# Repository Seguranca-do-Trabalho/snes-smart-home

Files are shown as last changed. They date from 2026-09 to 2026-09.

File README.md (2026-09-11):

# Super Famicom / SNES Smart Home & Diagnostics Cartridge V1.0

Custom smart cartridge for the **Super Famicom / SNES (SHVC-001)** console with bidirectional **Home Assistant** integration, bench telemetry, Wi-Fi 6 / BLE / Thread connectivity, and industrial expansion bus.

Designed to run on real hardware and emulators, with a 100% data-driven architecture: **the ROM does not assume beforehand how many or what devices exist in the house**.

---

## 📷 Photos and ROM Screenshots on Super Nintendo

| Page 1: Lighting, Garage, Climate and Fan | Page 2: Lock, Spotify, Alarm and Switch |
|:---:|:---:|
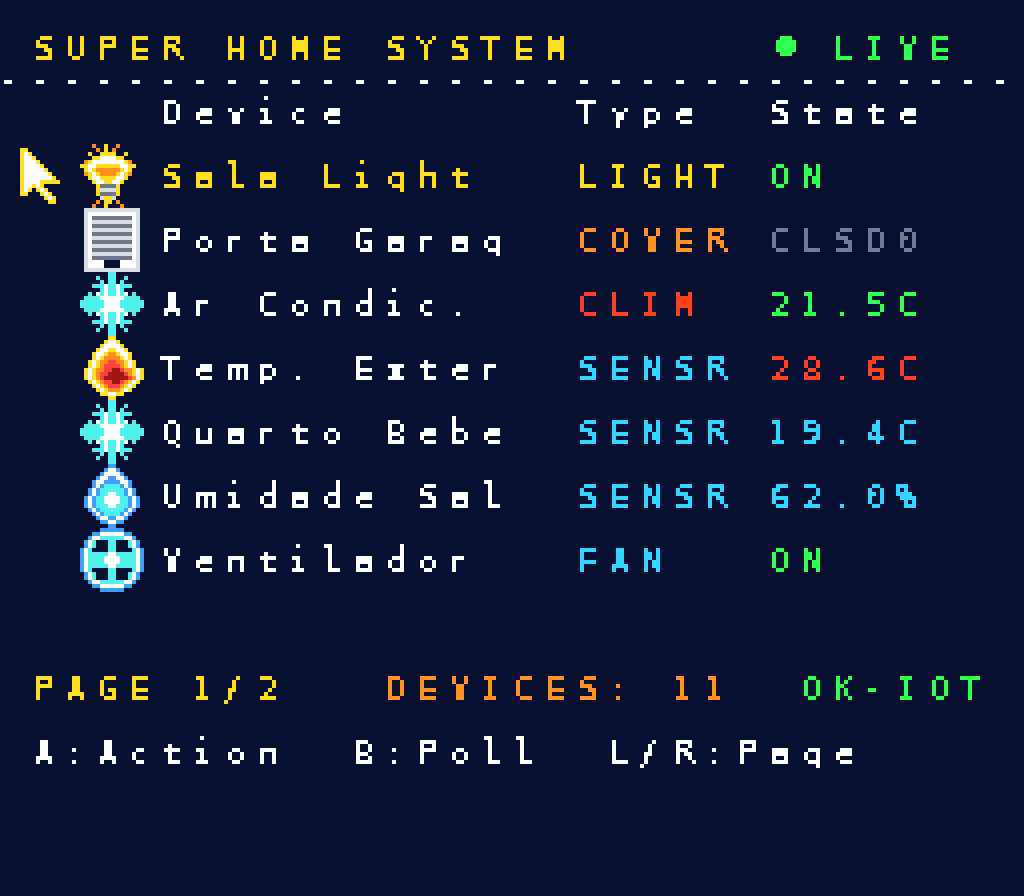
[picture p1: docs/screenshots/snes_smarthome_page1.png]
Page 1
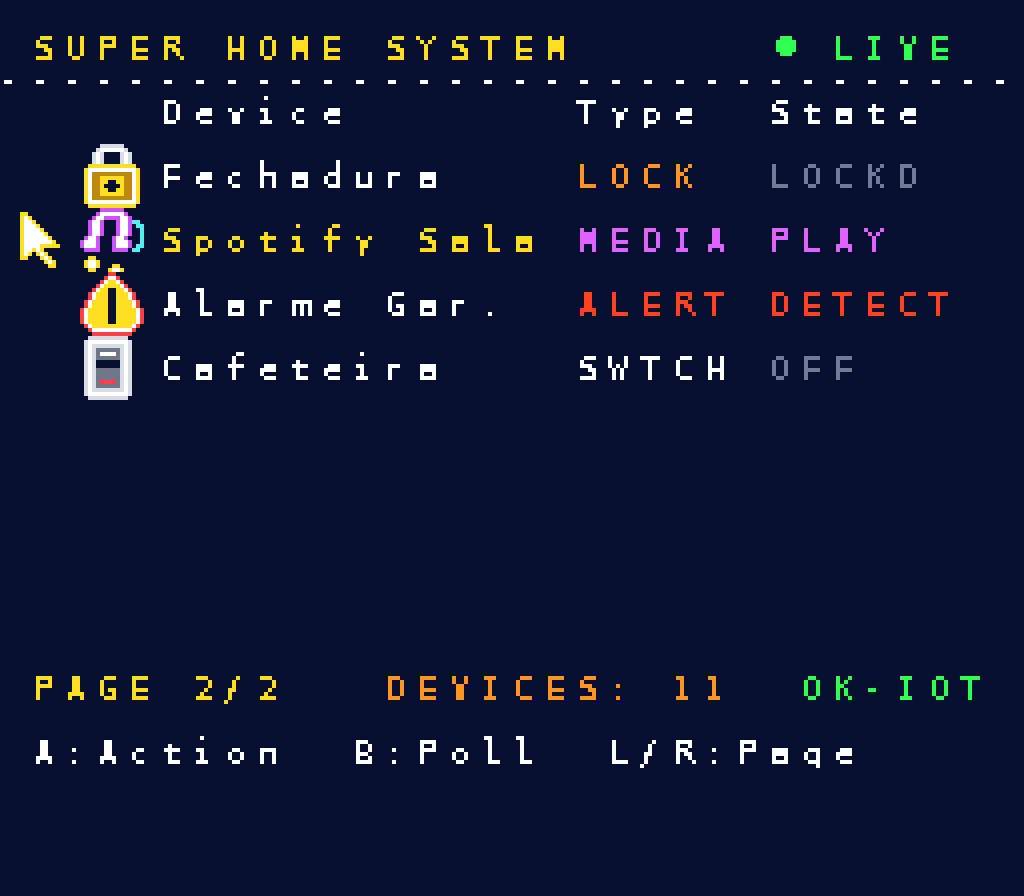
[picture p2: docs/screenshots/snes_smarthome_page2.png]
Page 2
|  |  |

### Retro Arcade CRT Simulation (Scanlines & PVM Phosphor)
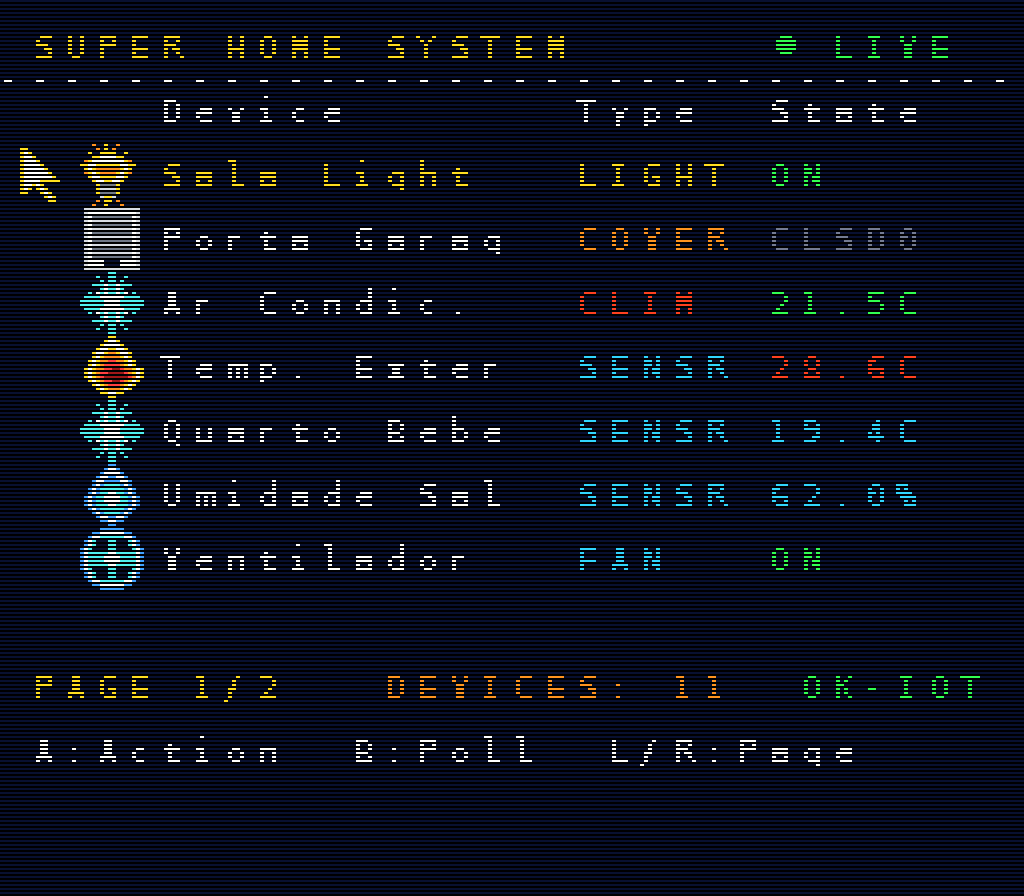
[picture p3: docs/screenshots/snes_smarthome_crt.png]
CRT View


---

## 1. System Architecture

```text
       ┌────────────────────────┐
       │     Home Assistant     │ (Server / Home)
       └───────────┬────────────┘
                   │ REST (GET /api/states) / WebSocket (state_changed)
                   ▼
       ┌────────────────────────┐
       │   Python Bridge / LAN  │ (Domain translation and normalization)
       └───────────┬────────────┘
                   │ Wi-Fi 802.11ax / TCP / Compact protocol 'SH 01'
                   ▼
┌───────────────────────────────────────────────────────────────┐
│              PHYSICAL SUPER FAMICOM / SNES CARTRIDGE           │
│                                                               │
│   ┌────────────────────┐          ┌───────────────────────┐   │
│   │   ESP32-C6-MINI    │◄─SPI/UART─┤        RP2350B        │   │
│   │ (Wi-Fi 6 / Thread) │          │  (Dual M33, 520KB)    │   │
│   └────────────────────┘          │  Mailbox in SRAM      │   │
│                                   └───────────┬───────────┘   │
│                                               │               │
│   ┌────────────────────┐          ┌───────────▼───────────┐   │
│   │   SST39VF040       │          │   74LVC Shifters      │   │
│   │  (Flash Boot ROM)  │          │   (5V TTL ◄─► 3.3V)   │   │
│   └─────────┬──────────┘          └───────────┬───────────┘   │
│             │                                 │               │
└─────────────┼─────────────────────────────────┼───────────────┘
              ▼                                 ▼
       ┌────────────────────────────────────────────────────────┐
       │                SNES 62-Pin Cartridge Bus               │
       │   (W65C816S CPU @ 3.58MHz, PPU Mode 1, OAM Sprites)    │
       └────────────────────────────────────────────────────────┘
```

### Architecture Principles
1. **Complexity Isolation:** The SNES does not process JSON, TLS, Wi-Fi, or HTTP. The ESP32-C6 handles all networking and security; the RP2350B normalizes state into a memory-mapped buffer (SRAM / Mailbox); the SNES only reads clean binary data.
2. **Dynamic Interface:** Layout is calculated at runtime. If you add 10 lights in Home Assistant, the SNES screen automatically creates new rows and pages. If you remove an outlet, it disappears from the ROM without recompiling the game.
3. **Instant Boot:** The parallel NOR Flash (512 KB) ensures immediate boot on the console (< 50 ms), while the coprocessors bring up networking in the background.

---

## 2. Repository Structure

```text
snes-smart-home/
├── snes/                      # SNES ROM source code (C + 65816 Assembly)
│   ├── src/
│   │   ├── main.c             # Main game loop and vblank (C)
│   │   ├── ui.c               # Screen rendering, 8 CGRAM palettes, pagination and sprites (C)
│   │   ├── ui.h
│   │   ├── audio.c            # SPC700 sound driver (C)
│   │   ├── audio.h
│   │   ├── cart_hw.asm        # Low-level bus driver in pure 65816 Assembly
│   │   ├── cart_hw.h          # C header for ASM routine calls
│   │   ├── cartio.c           # Cartridge I/O (SRAM mailbox + sim fallback) (C)
│   │   ├── cartio.h
│   │   └── config.h           # Display settings, limits, and SIMULATOR fallback
│   ├── assets/                # Converted bitmaps (font and icons)
│   │   ├── font.bmp           # 8x8 bitmap font
│   │   ├── icons.bmp          # 20 16x16 sprites for domains (light, door, fan, etc.)
│   │   └── make_icons.py      # Procedural generator for the 16x320 sprite sheet
│   ├── res/                   # Audio resources for smconv
│   │   └── soundbank.it       # ImpulseTracker tracker with samples and SFX
│   ├── data.asm               # Graphic data inclusion in ROM (WLA-DX)
│   ├── Makefile               # PVSnesLib 4.6.0 build script with smconv
│   └── super_home.sfc         # Compiled 256 KB ROM (LoROM SlowROM)
│
├── firmware/                  # Cartridge Coprocessor Firmware
│   ├── esp32/                 # Wi-Fi 6 / Thread Gateway (C / ESP-IDF)
│   │   ├── main/main.c        # Home Assistant REST Client + SPI Master
│   │   └── CMakeLists.txt
│   └── rp2350/                # SNES 62-pin Bus Emulator (C + PIO Assembly)
│       ├── main.c             # Dual-Core M33 Management and SRAM Mailbox
│       ├── snes_bus.pio       # PIO state machine for /RD and /WR cycles (<120ns)
│       └── CMakeLists.txt
│
├── hardware/                  # Complete KiCad 10 Electronic Design
│   ├── snes_smarthome_cartridge.kicad_pro   # KiCad Project
│   ├── snes_smarthome_cartridge.kicad_sch   # Root Schematic
│   ├── 01_SNES_BUS_AND_CIC.kicad_sch        # 62-pin connector + SuperCIC
│   ├── 02_LEVEL_SHIFTERS_AND_FLASH.kicad_sch# 5V<->3.3V Shifters + Boot Flash
│   ├── 03_RP2350_SUBSYSTEM.kicad_sch        # RP2350B MCU, QSPI 16MB, USB-C
│   ├── 04_ESP32C6_WIFI_IOT.kicad_sch        # ESP32-C6-MINI, Wi-Fi 6, RGB LED
│   ├── 05_PERIPHERALS_AND_POWER.kicad_sch   # MicroSD, RTC DS3231, RS485, Buck
│   ├── snes_smarthome_schematics.pdf        # Complete multi-sheet PDF
│   ├── BOM.md                               # Detailed Bill of Materials
│   ├── BOM.csv                              # BOM formatted with LCSC codes
│   └── PCBWAY_SPECS.md                      # PCBWay manufacturing rules
│
├── bridge/                    # Python Bridge (Home Assistant <-> Cartridge)
│   ├── ha_bridge.py           # REST polling, HTTP server, and TCP socket
│   └── requirements.txt
│
├── tests/                     # Automated Test Suite (Python)
│   └── test_system.py         # ROM integrity, protocol, and mailbox tests
│
├── docs/                      # Test documentation, captures, and architecture
│   ├── screenshots/           # High-resolution photos and screen captures
│   ├── architecture.md
│   ├── pin-mapping.md         # Complete pin mapping and signaling
│   └── test-plan.md
│
├── scripts/                   # Rendering and build utilities
│   └── generate_screenshots.py# Pixel-perfect and CRT screenshot generator
│
├── build-rom.sh               # ROM build script (1 click)
├── docker-compose.yml         # Local environment with Home Assistant + Bridge
└── README.md                  # This document
```

---

## 3. How to Compile the SNES ROM

### Prerequisites
- Linux x86_64 with `make` and `gcc`.
- **PVSnesLib 4.6.0** (installed in `/home/forg3/tools/pvsneslib` or configured via `PVSNESLIB_HOME`).

### Compilation
```bash
./build-rom.sh
```
The script will compile the graphic assets (`gfx4snes`), the C code (`816-tcc`), the assembler (`wla-65816`), run instruction optimization (`816-opt`), and generate the ROM at:
```text
snes/super_home.sfc
```

### Running in an Emulator
The ROM can be opened in any standard emulator (**bsnes**, **snes9x**, **Mesen 2**):
```bash
flatpak run com.snes9x.Snes9x snes/super_home.sfc
# or
flatpak run dev.bsnes.bsnes snes/super_home.sfc
```
In an emulator without the physical RP2350 hardware connected, the cartridge detects the absence of the `SH 01` signature at the SRAM address and activates **SIMULATOR** mode, allowing page navigation with `L` and `R`, entity selection with the D-pad, and state toggling with the `A` button.

### ROM Audiovisual Features

#### 1. Pixel Art Sprites and Animations (16×16 OAM)
The sprite sheet contains 20 themed icons (`snes/assets/icons.bmp` generated via `make_icons.py`):
- **Light (`light`):** Off incandescent bulb vs. on with golden radiant rays.
- **Switch (`switch`):** Industrial rocker switch with green LED indicator.
- **Garage / Gate (`cover`):** Closed gate vs. open with stylized retro sports car.
- **Lock (`lock`):** Closed padlock (locked) vs. open shackle (unlocked).
- **Fan (`fan`):** 4-blade propeller that **spins in real time**, alternating between 0° and 45° when powered on.
- **Climate (`climate`):** Snowflake for cooling / cold vs. orange flame for heating (> 24°C).
- **Sensors (`sensor`):** Blue droplet for humidity (%) vs. power bolt for watts/volts vs. thermometer.
- **Security (`binary_sensor`):** Green shield in safe state vs. warning triangle on alert.
- **Media (`media_player`):** Speaker in pause vs. equalizer with musical notes when playing.
- **Dynamic Cursor:** Indicator arrow with 2-frame animation and sinusoidal bounce effect to the left of the selected device.

#### 2. SPC700 Sound Effects (Sony DSP)
The cartridge integrates a Tracker soundbank (`snes/res/soundbank.it` compiled via `smconv` in ROM bank 5):
- `UP` / `DOWN`: Crisp percussive marimba when moving the cursor.
- `L` / `R`: Tactile acoustic click when changing pages.
- `A` (Turn On): Ascending melodic chime when activating/opening a device.
- `A` (Turn Off): Low-tone tap when deactivating/closing.
- `B` (Polling): Soft Home Assistant synchronization chime.

#### 3. Colored Text Palettes (BG Mode 1 - 8 CGRAM Palettes)
Device texts receive semantic colors based on type and state:
- **Gold (`PAL_GOLD`):** Main title, selected item, and page indicator.
- **Electric Cyan (`PAL_CYAN`):** Cold temperature (< 21°C) and humidity (%).
- **Fire Orange (`PAL_ORANGE`):** Hot temperature (> 25°C) and sensor alerts.
- **Emerald Green (`PAL_GREEN`):** States `"ON"`, `"OPEN"`, `"UNLKD"` and thermal comfort (21°C to 25°C).
- **Neutral Gray (`PAL_GRAY`):** Off states (`"OFF"`, `"CLSD"`, `"LOCKD"`).
- **Neon Purple (`PAL_PURPLE`):** Media devices (`"PLAY"`).
- **Amber (`PAL_AMBER`):** Device counters and warnings.

### ROM Architecture (C + Pure 65816 Assembly)
The ROM uses a hybrid high-level and low-level structure:
- **C (`816-tcc`):** GUI management, dynamic pagination, animations, font rendering, and state machines (`snes/src/main.c`, `snes/src/ui.c`, `snes/src/audio.c`).
- **Pure 65816 Assembly (`wla-65816`):** The [`snes/src/cart_hw.asm`](snes/src/cart_hw.asm) module implements low-level routines with 24-bit long addressing (`$700000` to `$7007FF`):
  - `cart_hw_probe()`: Atomic probe of the `'S', 'H', 0x01` signature on the cartridge SRAM bus.
  - `cart_hw_send_cmd()`: Atomic write to RP2350 command registers (`0x07F0..0x07F3`) with memory barrier and handshake flag.
  - `data.asm`: Graphic data bank allocation in `.rodata1`.

### Coprocessor Firmware
To ensure communication without overloading the SNES CPU, the cartridge features dedicated coprocessors:
1. **ESP32-C6 (`firmware/esp32/` - C / ESP-IDF):**
   - Connects to the Wi-Fi 6 (802.11ax) network.
   - Polls the Home Assistant Bridge (`/snapshot.bin`) or subscribes to TCP streams.
   - Validates integrity via CRC16 Modbus.
   - Sends snapshots and receives commands from the SNES via SPI bus at 10 MHz.
2. **RP2350B (`firmware/rp2350/` - C + PIO Assembly):**
   - **Core 0 + PIO (`snes_bus.pio`):** Emulates dual-port SRAM responding to SNES 62-pin bus `/RD` and `/WR` cycles in under 120 ns.
   - **Core 1:** Synchronizes buffers with the ESP32 via SPI and dispatches commands generated by the player.

### Automated ROM and Protocol Tests
The repository includes a complete automated test suite in Python:
```bash
python3 -m unittest discover -s tests -p "test_*.py" -v
```
The tests cover:
- Binary integrity of the 256 KB ROM and LoROM header checksum complement calculation.
- Serialization and deserialization of the compact binary protocol (`SH\x01`) and CRC16/Modbus (`0xA001`) algorithm validation.
- Home Assistant domain and service mapping and normalization.
- Alignment of command register offsets in cartridge memory.

---

## 4. Hardware and Specifications for PCBWay

The complete schematic was developed and validated with **KiCad 10.0.6** (`0 ERC violations`).

### Critical Fabrication Rules (PCBWay / JLCPCB)
When submitting files for manufacturing, you must select:
1. **Board Thickness: 1.2 mm** (The Super Famicom female connector was designed for 1.2 mm. 1.6 mm boards damage and warp the console's contact pins.)
2. **Edge Pitch: 2.50 mm Metric** (Do not use 2.54 mm / 0.1", as the cumulative error across 31 pins causes short circuits.)
3. **Gold Fingers with 30° Bevel (30° Edge Beveling):** Essential for the board to slide smoothly into the slot without damaging the gold contacts.
4. **Surface Finish:** **ENIG** (Electroless Nickel Immersion Gold) or **Hard Gold** on edge contacts.
5. **Layer Count: 4 Layers** (Top: Signals and RF Antenna / In1: Solid GND / In2: 3.3V and 5V / Bottom: Signals and back bus).

### Bill of Materials and LCSC Codes
The component list includes codes ready for turnkey SMT assembly:
- **RP2350B:** Dual Cortex-M33, 520KB SRAM, 48 GPIOs (QFN-80)
- **W25Q128JVSIQ:** 16MB QSPI Flash ([C97521](https://www.lcsc.com/product-detail/NOR-Flash_Winbond-Elec-W25Q128JVSIQ_C97521.html))
- **ESP32-C6-MINI-1-N4:** Wi-Fi 6 + BLE 5 + Thread ([C5248554](https://www.lcsc.com/product-detail/WiFi-Modules_Espressif-Systems-ESP32-C6-MINI-1-N4_C5248554.html))
- **SST39VF040-70-4C-WHE:** 512KB Parallel Boot ROM ([C129525](https://www.lcsc.com/product-detail/NOR-Flash_Microchip-Tech-SST39VF040-70-4C-WHE_C129525.html))
- **74LVC541APW:** 5V -> 3.3V Buffer ([C5975](https://www.lcsc.com/product-detail/Buffers-Drivers-Receivers-Transceivers_Nexperia-74LVC541APW-118_C5975.html))
- **SN74LVC8T245PWR:** 5V <-> 3.3V Data Transceiver ([C6207](https://www.lcsc.com/product-detail/Buffers-Drivers-Receivers-Transceivers_Texas-Instruments-SN74LVC8T245PWR_C6207.html))
- **PIC12F629-I/SN:** SuperCIC Lockout Bypass ([C20967](https://www.lcsc.com/product-detail/Microcontroller-Units-MCUs-MPUs-SOCs_Microchip-Tech-PIC12F629-I-SN_C20967.html))
- **SY8089AAAC:** 5V -> 3.3V 2A Synchronous Buck ([C28674](https://www.lcsc.com/product-detail/DC-DC-Converters_Silergy-Corp-SY8089AAAC_C28674.html))
- **DS3231MZ+:** High-precision MEMS RTC ([C16719](https://www.lcsc.com/product-detail/Real-Time-Clocks-RTC_Analog-Devices-Maxim-Integrated-DS3231MZ_C16719.html))
- **SP3485CN-L/TR:** 3.3V RS-485 Transceiver ([C6960](https://www.lcsc.com/product-detail/RS-485-RS-422-ICs_MaxLinear-SP3485CN-L-TR_C6960.html))

*See [`hardware/BOM.md`](hardware/BOM.md) and [`hardware/BOM.csv`](hardware/BOM.csv) for the full list.*

---

## 5. Compact Binary Protocol (V1)

The cartridge communicates with the bridge using compact frames with checksum:

```text
[Header 2B: 'S' 'H'] [Version: 0x01] [Total Entities: 1B] [Entity Records...] [CRC16/Modbus 2B]
```

### Each Entity Format:
```text
u8  domain               (1: light, 2: switch, 3: cover, 4: lock, 5: fan, 6: climate, 7: sensor...)
u8  state_code           (0: off/closed, 1: on/open, 2: numeric value / other)
u8  features             (capability bitmask: on/off, brightness, temperature, percentage)
u8  name_len             (friendly name length in characters)
u16 numeric_value_x100   (value multiplied by 100 in little-endian, or 0xFFFF if null)
u8  name[name_len]       (ASCII string of the name)
```

### Command Mailbox (SNES -> RP2350 -> Home Assistant):
- `0x07F0`: Command code (`1`: Toggle ON/OFF, `2`: Open/Close Cover)
- `0x07F1`: Target entity index
- `0x07F2`: Parameter / New state
- `0x07F3`: Handshake flag (SNES writes `0x01`; RP2350 clears to `0x00` after dispatching via ESP32)

---

## 6. Testing with Home Assistant

1. Start the test environment:
   ```bash
   podman compose up -d homeassistant
   # or
   docker compose up -d homeassistant
   ```
2. Obtain a long-lived access token in Home Assistant (`http://127.0.0.1:8123`).
3. Export the token and start the bridge:
   ```bash
   export HA_TOKEN="your_token_here"
   python3 bridge/ha_bridge.py
   ```
4. Query the generated snapshot:
   ```bash
   curl http://127.0.0.1:8790/entities
   curl http://127.0.0.1:8790/snapshot.bin --output snap.bin
   ```
5. Send a test command:
   ```bash
   curl -X POST http://127.0.0.1:8790/command \
     -H "Content-Type: application/json" \
     -d '{"entity_id":"light.sala_light","action":"off"}'
   ```

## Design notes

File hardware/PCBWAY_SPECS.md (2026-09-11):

# PCBWay Fabrication Guidelines for SNES / Super Famicom Cartridge

When configuring the PCB fabrication order on **PCBWay** (or JLCPCB), you must use the following parameters:

---

### 1. Critical Board Specifications

| Parameter | Recommended Value | Reason / Critical Note |
| :--- | :--- | :--- |
| **Layers** | **4 Layers** | Required for 21MHz bus signal integrity, continuous GND plane, and ESP32-C6 RF impedance. |
| **PCB Thickness** | **1.2 mm** (or 1.25 mm) | **CRITICAL:** The original Super Famicom / SNES connector was designed for **1.2 mm** PCBs. Standard 1.6 mm boards are too thick and will damage/warp the console slot blades. 0.8 mm boards are too loose. |
| **Surface Finish** | **ENIG (Electroless Nickel Immersion Gold)** or **Hard Gold (Gold Fingers)** | Abrasion-resistant immersion gold for insertions and oxidation protection over years of use. |
| **Gold Fingers** | **Yes** | Select to apply reinforced gold plating on the 62 edge contacts. |
| **Edge Chamfering / Beveling** | **Yes, 30° Chamfer** (30 degrees) | **CRITICAL:** Creates a 30° angle chamfer on the bottom edge of the contacts, allowing the cartridge to slide smoothly into the console slot without snagging or lifting pads. |
| **Connector Pitch** | **2.50 mm** (Metric) | Verify the footprint uses a 2.50 mm pitch (not 2.54 mm). |
| **Solder Mask** | Blue / Matte Black / Gray | Your preferred aesthetic. |
| **Silkscreen** | White | High legibility text. |
| **Copper Weight** | 1 oz (outer) / 0.5 oz (inner) | Industrial standard. |
| **Material** | FR-4 Standard (Tg 150-170) | High thermal stability during reflow. |

---

### 2. Suggested 4-Layer Stackup (1.2mm)

```text
Layer 1 (Top):     High-speed signals, SMD components, RF antenna
Layer 2 (In1):     Solid Ground Plane (GND)
Layer 3 (In2):     Power Plane (+3.3V Digital + 5V SNES)
Layer 4 (Bottom):  Control signals, secondary bus, rear edge contacts
```

---

### 3. Special Routing & Layout Considerations

1. **ESP32-C6 Antenna:**
   - Position the ESP32-C6-MINI module on the top edge of the cartridge (away from the 62-pin connector).
   - Keep the area under the module antenna completely free of copper (no traces and no GND planes on all 4 layers).
2. **RS-485 Differential:**
   - Route A and B traces as a differential pair with 120 ohm coupled impedance.
3. **Data Bus (D0..D7):**
   - Matched length between the 74LVC buffers and the RP2350/Flash.
4. **Buck Converter Decoupling:**
   - Place C_IN1, L1, and C_OUT1 as close as possible to the SY8089 pins to minimize the 1.5 MHz switching loop.

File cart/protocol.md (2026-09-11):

# Cartridge ↔ Home Assistant protocol V1

The ROM does not speak HTTP, JSON, TLS, or MQTT. The cartridge MCU handles that and delivers a compact snapshot to the ROM.

## Entity record

```text
u8  domain
u8  state_code
u8  features
u8  name_len
u16 numeric_value_x100   ; 0xFFFF = no value
u8  name[name_len]
```

Domains: 1 light, 2 switch, 3 cover, 4 lock, 5 fan, 6 climate, 7 sensor, 8 binary_sensor, 9 media_player, 255 other.

Feature bits: bit0 on/off, bit1 brightness, bit2 open/close, bit3 lock/unlock, bit4 set_value, bit5 temperature, bit6 percentage.

## Snapshot

`53 48 01 COUNT RECORDS CRC16` — CRC16/Modbus, little-endian.

## Commands

`01 SET_ON_OFF`, `02 SET_OPEN_CLOSE`, `03 SET_VALUE`, `04 REQUEST_REFRESH`.

The UI never assumes that a light or door exists. The list is the sole source for rendering.

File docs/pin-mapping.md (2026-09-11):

# SNES Smart Home — Complete Pin Mapping

Reference document for all hardware signals across the 5-sheet KiCad schematic.

---

## 1. SNES 62-Pin Edge Connector (P1)

Standard SHVC-001 cartridge edge connector. Gold fingers, 2.50 mm pitch, 1.2 mm PCB thickness.

### Signal Summary

| Category | Count | Pins |
|:---|:---|:---|
| Power (+5V) | 2 | 27, 58 |
| Ground (GND) | 2 | 5, 36 |
| Data (D0-D7) | 8 | 19-22, 50-53 |
| Address (A0-A15)| 16 | 6-17, 37-40 |
| Bank (A16-A23)  | 8 | 41-48 |
| Control | 6 | 18, 23, 26, 49, 54, 57 |
| CIC | 4 | 24, 25, 55, 56 |
| NC / Reserved | 18 | 1-4, 7-16, 28-35, 51-52 (alt) |

### Complete Pin Table (1-62, Top Side)

| Pin | Signal | Direction  | Description |
|:----|:---|:---|:---|
| 1 | NC | — | No connect |
| 2 | NC | — | No connect |
| 3 | NC | — | No connect |
| 4 | NC | — | No connect |
| 5 | **GND** | Power | Ground |
| 6 | SNES_A0 | Input → | Address bus bit 0 |
| 7 | SNES_A1 | Input → | Address bus bit 1 |
| 8 | SNES_A2 | Input → | Address bus bit 2 |
| 9 | SNES_A3 | Input → | Address bus bit 3 |
| 10  | SNES_A4 | Input → | Address bus bit 4 |
| 11  | SNES_A5 | Input → | Address bus bit 5 |
| 12  | SNES_A6 | Input → | Address bus bit 6 |
| 13  | SNES_A7 | Input → | Address bus bit 7 |
| 14  | SNES_A8 | Input → | Address bus bit 8 |
| 15  | SNES_A9 | Input → | Address bus bit 9 |
| 16  | SNES_A10 | Input → | Address bus bit 10 |
| 17  | SNES_A11 | Input → | Address bus bit 11 |
| 18  | **/IRQ** | Output ← | Interrupt request (active low) |
| 19  | SNES_D0 | Bidir ↔ | Data bus bit 0 |
| 20  | SNES_D1 | Bidir ↔ | Data bus bit 1 |
| 21  | SNES_D2 | Bidir ↔ | Data bus bit 2 |
| 22  | SNES_D3 | Bidir ↔ | Data bus bit 3 |
| 23  | **/RD** | Input → | Read strobe (active low) |
| 24  | CIC_DAT1 | I/O ↔ | CIC data line 1 (lockout) |
| 25  | CIC_RST | Output ← | CIC reset |
| 26  | **/RESET** | Input → | System reset (active low) |
| 27  | **+5V_SNES**  | Power | +5V from console |
| 28  | NC | — | No connect |
| 29  | NC | — | No connect |
| 30  | NC | — | No connect |
| 31  | NC | — | No connect |
| 32  | NC | — | No connect |
| 33  | NC | — | No connect |
| 34  | NC | — | No connect |
| 35  | NC | — | No connect |
| 36  | **GND** | Power | Ground |
| 37  | SNES_A12 | Input → | Address bus bit 12 |
| 38  | SNES_A13 | Input → | Address bus bit 13 |
| 39  | SNES_A14 | Input → | Address bus bit 14 |
| 40  | SNES_A15 | Input → | Address bus bit 15 |
| 41  | SNES_A16 | Input → | Bank address bit 0 (A16) |
| 42  | SNES_A17 | Input → | Bank address bit 1 (A17) |
| 43  | SNES_A18 | Input → | Bank address bit 2 (A18) |
| 44  | SNES_A19 | Input → | Bank address bit 3 (A19) |
| 45  | SNES_A20 | Input → | Bank address bit 4 (A20) |
| 46  | SNES_A21 | Input → | Bank address bit 5 (A21) |
| 47  | SNES_A22 | Input → | Bank address bit 6 (A22) |
| 48  | SNES_A23 | Input → | Bank address bit 7 (A23) |
| 49  | **/ROMSEL** | Input → | ROM chip select /CART (active low) |
| 50  | SNES_D4 | Bidir ↔ | Data bus bit 4 |
| 51  | SNES_D5 | Bidir ↔ | Data bus bit 5 |
| 52  | SNES_D6 | Bidir ↔ | Data bus bit 6 |
| 53  | SNES_D7 | Bidir ↔ | Data bus bit 7 |
| 54  | **/WR** | Input → | Write strobe (active low) |
| 55  | CIC_DAT2 | I/O ↔ | CIC data line 2 (console) |
| 56  | CIC_CLK | Output ← | CIC clock (76 kHz) |
| 57  | **PHI2** | Input → | CPU clock (3.58 MHz NTSC / 3.52 PAL)|
| 58  | **+5V_SNES**  | Power | +5V from console |
| 59  | NC | — | No connect |
| 60  | NC | — | No connect |
| 61  | NC | — | No connect |
| 62  | NC | — | No connect |

---

## 2. PIC12F629 SuperCIC Pin Mapping (U1)

The PIC12F629 implements the SuperCIC lockout bypass, enabling the cartridge to work on both lockout and non-lockout consoles (NTSC/PAL auto-detect).

### SOIC-8 Package

| Pin | Signal | Direction | Description |
|:----|:---|:---|:---|
| 1 | VDD | Power | +3V3 (from SY8089 buck regulator) |
| 2 | RA5 / CIC_DAT1 | I/O ↔  | Bidirectional CIC data (to SNES pin 24)  |
| 3 | RA4 / CIC_DAT2 | I/O ↔  | Bidirectional CIC data (to SNES pin 55)  |
| 4 | RA3 / CIC_RST  | Input | CIC reset from console (SNES pin 25) |
| 5 | RA2 / CIC_CLK  | Output  | CIC clock to console (SNES pin 56) |
| 6 | RA1 | NC | Unused (or debug LED) |
| 7 | RA0 | NC | Unused (or NTSC/PAL select jumper) |
| 8 | VSS | Power | GND |

### SuperCIC Operation

1. On power-up, the PIC emulates the CIC lockout chip handshake.
2. Console asserts /RESET → PIC drives CIC_CLK at 76 kHz.
3. CIC_DAT1 and CIC_DAT2 exchange challenge/response tokens.
4. If handshake succeeds → console releases /ROMSEL and bus access begins.
5. NTSC/PAL auto-detected from CIC_CLK frequency (76.0 kHz NTSC / 76.1 kHz PAL).

---

## 3. Inter-Sheet Signal Routing

All signals between schematic sheets pass through hierarchical labels. The table below maps every cross-sheet signal.

### Sheet 1 → Sheet 2 (SNES Bus → Level Shifters)

| Signal | SNES Pin | U2/U3 Input | U2/U3 Output | Target IC |
|:---|:---|:---|:---|:---|
| SNES_A0 | 6 | 74LVC541 U2 | BUS_A0 | RP2350, U5 |
| SNES_A1 | 7 | 74LVC541 U2 | BUS_A1 | RP2350, U5 |
| SNES_A2 | 8 | 74LVC541 U2 | BUS_A2 | RP2350, U5 |
| SNES_A3 | 9 | 74LVC541 U2 | BUS_A3 | RP2350, U5 |
| SNES_A4 | 10 | 74LVC541 U2 | BUS_A4 | RP2350, U5 |
| SNES_A5 | 11 | 74LVC541 U2 | BUS_A5 | RP2350, U5 |
| SNES_A6 | 12 | 74LVC541 U2 | BUS_A6 | RP2350, U5 |
| SNES_A7 | 13 | 74LVC541 U2 | BUS_A7 | RP2350, U5 |
| SNES_A8 | 14 | 74LVC541 U3 | BUS_A8 | RP2350, U5 |
| SNES_A9 | 15 | 74LVC541 U3 | BUS_A9 | RP2350, U5 |
| SNES_A10 | 16 | 74LVC541 U3 | BUS_A10 | RP2350, U5 |
| SNES_A11 | 17 | 74LVC541 U3 | BUS_A11 | RP2350, U5 |
| SNES_A12 | 37 | 74LVC541 U3 | BUS_A12 | RP2350 |
| SNES_A13 | 38 | 74LVC541 U3 | BUS_A13 | RP2350 |
| SNES_A14 | 39 | 74LVC541 U3 | BUS_A14 | RP2350 |
| SNES_A15 | 40 | 74LVC541 U3 | BUS_A15 | RP2350 |
| /RD | 23 | 74LVC541 U2 | BUS_RD | RP2350, U4 |
| /WR | 54 | 74LVC541 U2 | BUS_WR | RP2350 |
| /ROMSEL | 49 | 74LVC541 U3 | BUS_ROMSEL | RP2350 |
| PHI2 | 57 | 74LVC541 U3 | BUS_PHI2 | RP2350 |
| SNES_D0-D3 | 19-22 | SN74LVC8T245 U4 | BUS_D0-D3 | RP2350, U5 |
| SNES_D4-D7 | 50-53 | SN74LVC8T245 U4 | BUS_D4-D7 | RP2350, U5 |

**Direction control:** U4 DIR pin = SNES /RD (read → SNES→BUS direction for active reads).

### Sheet 2 → Sheet 3 (Level Shifters → RP2350)

| Signal | Source | RP2350 GPIO | Function |
|:---|:---|:---|:---|
| BUS_D0 | U4 | GPIO0 | Data bus bit 0 |
| BUS_D1 | U4 | GPIO1 | Data bus bit 1 |
| BUS_D2 | U4 | GPIO2 | Data bus bit 2 |
| BUS_D3 | U4 | GPIO3 | Data bus bit 3 |
| BUS_D4 | U4 | GPIO4 | Data bus bit 4 |
| BUS_D5 | U4 | GPIO5 | Data bus bit 5 |
| BUS_D6 | U4 | GPIO6 | Data bus bit 6 |
| BUS_D7 | U4 | GPIO7 | Data bus bit 7 |
| BUS_A0 | U2 | GPIO8 | Address bus bit 0 |
| BUS_A1 | U2 | GPIO9 | Address bus bit 1 |
| BUS_A2 | U2 | GPIO10 | Address bus bit 2 |
| BUS_A3 | U2 | GPIO11 | Address bus bit 3 |
| BUS_A4 | U2 | GPIO12 | Address bus bit 4 |
| BUS_A5 | U2 | GPIO13 | Address bus bit 5 |
| BUS_A6 | U2 | GPIO14 | Address bus bit 6 |
| BUS_A7 | U2 | GPIO15 | Address bus bit 7 |
| BUS_A8 | U3 | GPIO16 | Address bus bit 8 |
| BUS_A9 | U3 | GPIO17 | Address bus bit 9 |
| BUS_A10 | U3 | GPIO18 | Address bus bit 10 |
| BUS_A11 | U3 | GPIO19 | Address bus bit 11 |
| BUS_A12 | U3 | GPIO20 | Address bus bit 12 |
| BUS_A13 | U3 | GPIO21 | Address bus bit 13 |
| BUS_A14 | U3 | GPIO22 | Address bus bit 14 |
| BUS_A15 | U3 | GPIO23 | Address bus bit 15 |
| BUS_/RD | U2 | GPIO24 | Read strobe (active low)|
| BUS_/WR | U2 | GPIO25 | Write strobe (active low)|
| BUS_/ROMSEL | U3 | GPIO26 | ROM chip select |
| BUS_PHI2 | U3 | GPIO27 | CPU clock (3.58 MHz) |
| BUS_/IRQ | RP2350 | GPIO28 | Interrupt to SNES |

### Sheet 3 → Sheet 4 (RP2350 ↔ ESP32-C6)

| Signal | RP2350 GPIO | ESP32-C6 Pin | Interface | Function |
|:---|:---|:---|:---|:---|
| SPI_SCK | GPIO29 | SPI_CLK | SPI0 | SPI clock |
| SPI_MOSI | GPIO30 | SPI_MOSI | SPI0 | Master Out Slave In|
| SPI_MISO | GPIO31 | SPI_MISO | SPI0 | Master In Slave Out|
| SPI_CS | GPIO32 | SPI_CS | SPI0 | Chip select |
| UART_TX | GPIO33 | UART_RX | UART0 | RP2350 → ESP32 |
| UART_RX | GPIO34 | UART_TX | UART0 | ESP32 → RP2350 |

### Sheet 3 → Sheet 5 (RP2350 ↔ Peripherals)

| Signal | RP2350 GPIO | Peripheral | Interface | Function |
|:---|:---|:---|:---|:---|
| I2C_SDA | GPIO35 | DS3231, Qwiic | I2C0 | Data line |
| I2C_SCL | GPIO36 | DS3231, Qwiic | I2C0 | Clock line |
| SD_SCK | GPIO37 | MicroSD J4 | SPI1 | SD clock |
| SD_MOSI | GPIO38 | MicroSD J4 | SPI1 | SD data in |
| SD_MISO | GPIO39 | MicroSD J4 | SPI1 | SD data out |
| SD_CS | GPIO40 | MicroSD J4 | SPI1 | SD chip select |
| RS485_TX | GPIO41 | SP3485 U11 | UART1 | RS-485 transmit |
| RS485_RX | GPIO42 | SP3485 U11 | UART1 | RS-485 receive |
| RS485_DE | GPIO41 (shared) | SP3485 U11  | GPIO | Driver Enable |

### Sheet 3 — Status & Configuration GPIOs

| Signal | RP2350 GPIO | Function |
|:---|:---|:---|
| LED_STATUS | GPIO43 | WS2812B RGB status LED |
| LED_WIFI | GPIO44 | Wi-Fi connection indicator |
| LED_HEARTBEAT| GPIO45 | Firmware alive indicator |
| JUMP_BOOTSEL | GPIO46 | BOOTSEL button input (active low) |
| JUMP_RST | GPIO47 | RESET button input (active low) |

---

## 4. Power Domain Mapping

### Domain: +5V_SNES (Console Supply)

| Source | Pin(s) | Distribution |
|:---|:---|:---|
| SNES Pin 27 | +5V_SNES | → PTC Fuse F1 (1.5A) → Schottky D4 (SS34) |
| SNES Pin 58 | +5V_SNES | → PTC Fuse F1 (1.5A) → Schottky D4 (SS34) |

**After protection:**
| Consumer | Input | Notes |
|:---|:---|:---|
| SY8089 Buck (U9) | 5V input | Converts to +3V3 |
| 74LVC541 U2 | VCC (5V side) | SNES-side supply |
| 74LVC541 U3 | VCC (5V side) | SNES-side supply |
| SN74LVC8T245 U4 | VCCA (5V side)| SNES-side supply |
| SST39VF040 U5 | VCC | Parallel Flash boot ROM |
| PIC12F629 U1 | — | Powered from +3V3, not +5V |

### Domain: +3V3 (Regulated Supply)

| Source | Consumer | Notes |
|:---|:---|:---|
| SY8089 (U9)  | RP2350B (U6) | Core + IO supply |
| SY8089 (U9)  | W25Q128 (U7) | QSPI Flash |
| SY8089 (U9)  | ESP32-C6 (U8) | Wi-Fi/BLE module |
| SY8089 (U9)  | 74LVC541 U2 | 3.3V-side supply |
| SY8089 (U9)  | 74LVC541 U3 | 3.3V-side supply |
| SY8089 (U9)  | SN74LVC8T245 U4 | 3.3V-side supply (VCCB) |
| SY8089 (U9)  | DS3231 (U10) | RTC |
| SY8089 (U9)  | SP3485 (U11) | RS-485 transceiver |
| SY8089 (U9)  | MicroSD (J4) | SD card slot |
| SY8089 (U9)  | I2C pullups (4.7k) | SDA/SCL bias |
| CR1220 (BT1) | DS3231 VBAT | RTC battery backup |

### Domain: GND (Common Ground)

| Source | Pin(s) | Distribution |
|:---|:---|:---|
| SNES Pin 5 | GND | Common ground plane |
| SNES Pin 36 | GND | Common ground plane |

All ICs share the same GND plane (4-layer PCB, In1 = solid GND).

### Power Tree Diagram

```text
SNES +5V_SNES (Pins 27, 58)
  │
  ├── F1 (PTC 1.5A) ── D4 (SS34 Schottky) ──┬── +5V protected
  │                                           │
  │     ┌─────────────────────────────────────┤
  │     │                                     │
  │     ▼                                     ▼
  │  U9 SY8089 Buck                     U2, U3, U4 (5V side)
  │  5V → 3.3V 2.0A                    U5 SST39VF040 Flash
  │     │
  │     ▼
  │  +3V3 Rail
  │     ├── U6 RP2350B
  │     ├── U7 W25Q128 QSPI
  │     ├── U8 ESP32-C6
  │     ├── U10 DS3231 RTC
  │     ├── U11 SP3485 RS-485
  │     ├── J4 MicroSD
  │     ├── U2, U3, U4 (3.3V side)
  │     ├── I2C pullups (4.7k)
  │     └── BT1 CR1220 → DS3231 VBAT (backup)
  │
GND (Pins 5, 36) ── Common ground plane (In1)
```

---

## 5. 74LVC Level Shifter Details

### U2 — 74LVC541APW (Octal Buffer, Unidirectional)

Translates SNES-side 5V signals to 3.3V bus for RP2350. Unidirectional (SNES → BUS).

| 74LVC541 Pin | Input (5V) | Output (3.3V) | 74LVC541 Pin |
|:---|:---|:---|:---|
| 2 (1A1) | SNES_A0 | BUS_A0 | 18 (1Y4) |
| 3 (1A2) | SNES_A1 | BUS_A1 | 17 (1Y3) |
| 4 (1A3) | SNES_A2 | BUS_A2 | 16 (1Y2) |
| 5 (1A4) | SNES_A3 | BUS_A3 | 15 (1Y1) |
| 7 (2A1) | SNES_A4 | BUS_A4 | 13 (2Y4) |
| 8 (2A2) | SNES_A5 | BUS_A5 | 12 (2Y3) |
| 9 (2A3) | SNES_A6 | BUS_A6 | 11 (2Y2) |
| 10 (2A4) | SNES_A7 | BUS_A7 | 10 (2Y1) |

OE1 (pin 1) = GND (always enabled)
OE2 (pin 19) = GND (always enabled)

### U3 — 74LVC541APW (Octal Buffer, Unidirectional)

| 74LVC541 Pin | Input (5V)  | Output (3.3V) | 74LVC541 Pin |
|:---|:---|:---|:---|
| 2 (1A1) | SNES_A8 | BUS_A8 | 18 (1Y4) |
| 3 (1A2) | SNES_A9 | BUS_A9 | 17 (1Y3) |
| 4 (1A3) | SNES_A10 | BUS_A10 | 16 (1Y2) |
| 5 (1A4) | SNES_A11 | BUS_A11 | 15 (1Y1) |
| 7 (2A1) | SNES_A12 | BUS_A12 | 13 (2Y4) |
| 8 (2A2) | SNES_A13 | BUS_A13 | 12 (2Y3) |
| 9 (2A3) | SNES_A14 | BUS_A14 | 11 (2Y2) |
| 10 (2A4) | SNES_A15 | BUS_A15 | 10 (2Y1) |

OE1 (pin 1) = GND, OE2 (pin 19) = GND

### U4 — SN74LVC8T245 (Bidirectional Transceiver)

8-bit bidirectional data bus translator. Direction controlled by /RD.

| 74LVC8T245 Pin | Side A (5V)  | Side B (3.3V) | 74LVC8T245 Pin |
|:---|:---|:---|:---|
| 2 (A0) | SNES_D0 | BUS_D0 | 23 (B0) |
| 3 (A1) | SNES_D1 | BUS_D1 | 22 (B1) |
| 4 (A2) | SNES_D2 | BUS_D2 | 21 (B2) |
| 5 (A3) | SNES_D3 | BUS_D3 | 20 (B3) |
| 6 (A4) | SNES_D4 | BUS_D4 | 19 (B4) |
| 7 (A5) | SNES_D5 | BUS_D5 | 18 (B5) |
| 8 (A6) | SNES_D6 | BUS_D6 | 17 (B6) |
| 9 (A7) | SNES_D7 | BUS_D7 | 16 (B7) |

| Control Pin | Signal | Function |
|:---|:---|:---|
| 1 (DIR) | BUS_RD | Direction: H = A→B, L = B→A |
| 11 (OE) | GND | Always enabled |

**DIR logic:** When /RD is LOW (active read), DIR = LOW → B→A (BUS→SNES). When /RD is HIGH, DIR = HIGH → A→B (SNES→BUS for writes).

---

## 6. SST39VF040 Flash Memory Map (U5)

| BUS_A0-A18 | BUS_D0-D7 | RP2350 GPIO | Function |
|:---|:---|:---|:---|
| BUS_A0 | BUS_D0 | GPIO0 | Data bit 0 |
| BUS_A1 | BUS_D1 | GPIO1 | Data bit 1 |
| BUS_A2 | BUS_D2 | GPIO2 | Data bit 2 |
| BUS_A3 | BUS_D3 | GPIO3 | Data bit 3 |
| BUS_A4 | BUS_D4 | GPIO4 | Data bit 4 |
| BUS_A5 | BUS_D5 | GPIO5 | Data bit 5 |
| BUS_A6 | BUS_D6 | GPIO6 | Data bit 6 |
| BUS_A7 | BUS_D7 | GPIO7 | Data bit 7 |
| BUS_A0-A17 | — | GPIO8-25 | Address bus |
| BUS_A18 | — | GPIO26 | Address bit 18 |

Flash control: CE (chip enable), OE (output enable), WE (write enable) — active low.

---

## 7. GPIO Allocation Summary (RP2350B — 48 GPIOs Used)

| GPIO Range | Count | Function | Direction |
|:---|:---|:---|:---|
| 0-7 | 8 | Data bus (BUS_D0-D7) | Bidir ↔ |
| 8-23 | 16 | Address bus (BUS_A0-A15) | Input → |
| 24 | 1 | BUS_/RD | Input → |
| 25 | 1 | BUS_/WR | Input → |
| 26 | 1 | BUS_/ROMSEL | Input → |
| 27 | 1 | BUS_PHI2 | Input → |
| 28 | 1 | BUS_/IRQ | Output ← |
| 29-32 | 4 | SPI0 to ESP32 (SCK,MOSI,MISO,CS) | Bidir ↔ |
| 33-34 | 2 | UART0 to ESP32 (TX, RX) | Bidir ↔ |
| 35-36 | 2 | I2C0 (SDA, SCL) | Bidir ↔ |
| 37-40 | 4 | SPI1 MicroSD (SCK,MOSI,MISO,CS)  | Bidir ↔ |
| 41-42 | 2 | UART1 RS-485 (TX, RX) | Bidir ↔ |
| 43 | 1 | WS2812B RGB LED | Output → |
| 44-45 | 2 | Status LEDs (WiFi, Heartbeat) | Output → |
| 46-47 | 2 | Button inputs (BOOTSEL, RST) | Input → |
| **Total**  | **48**| | |

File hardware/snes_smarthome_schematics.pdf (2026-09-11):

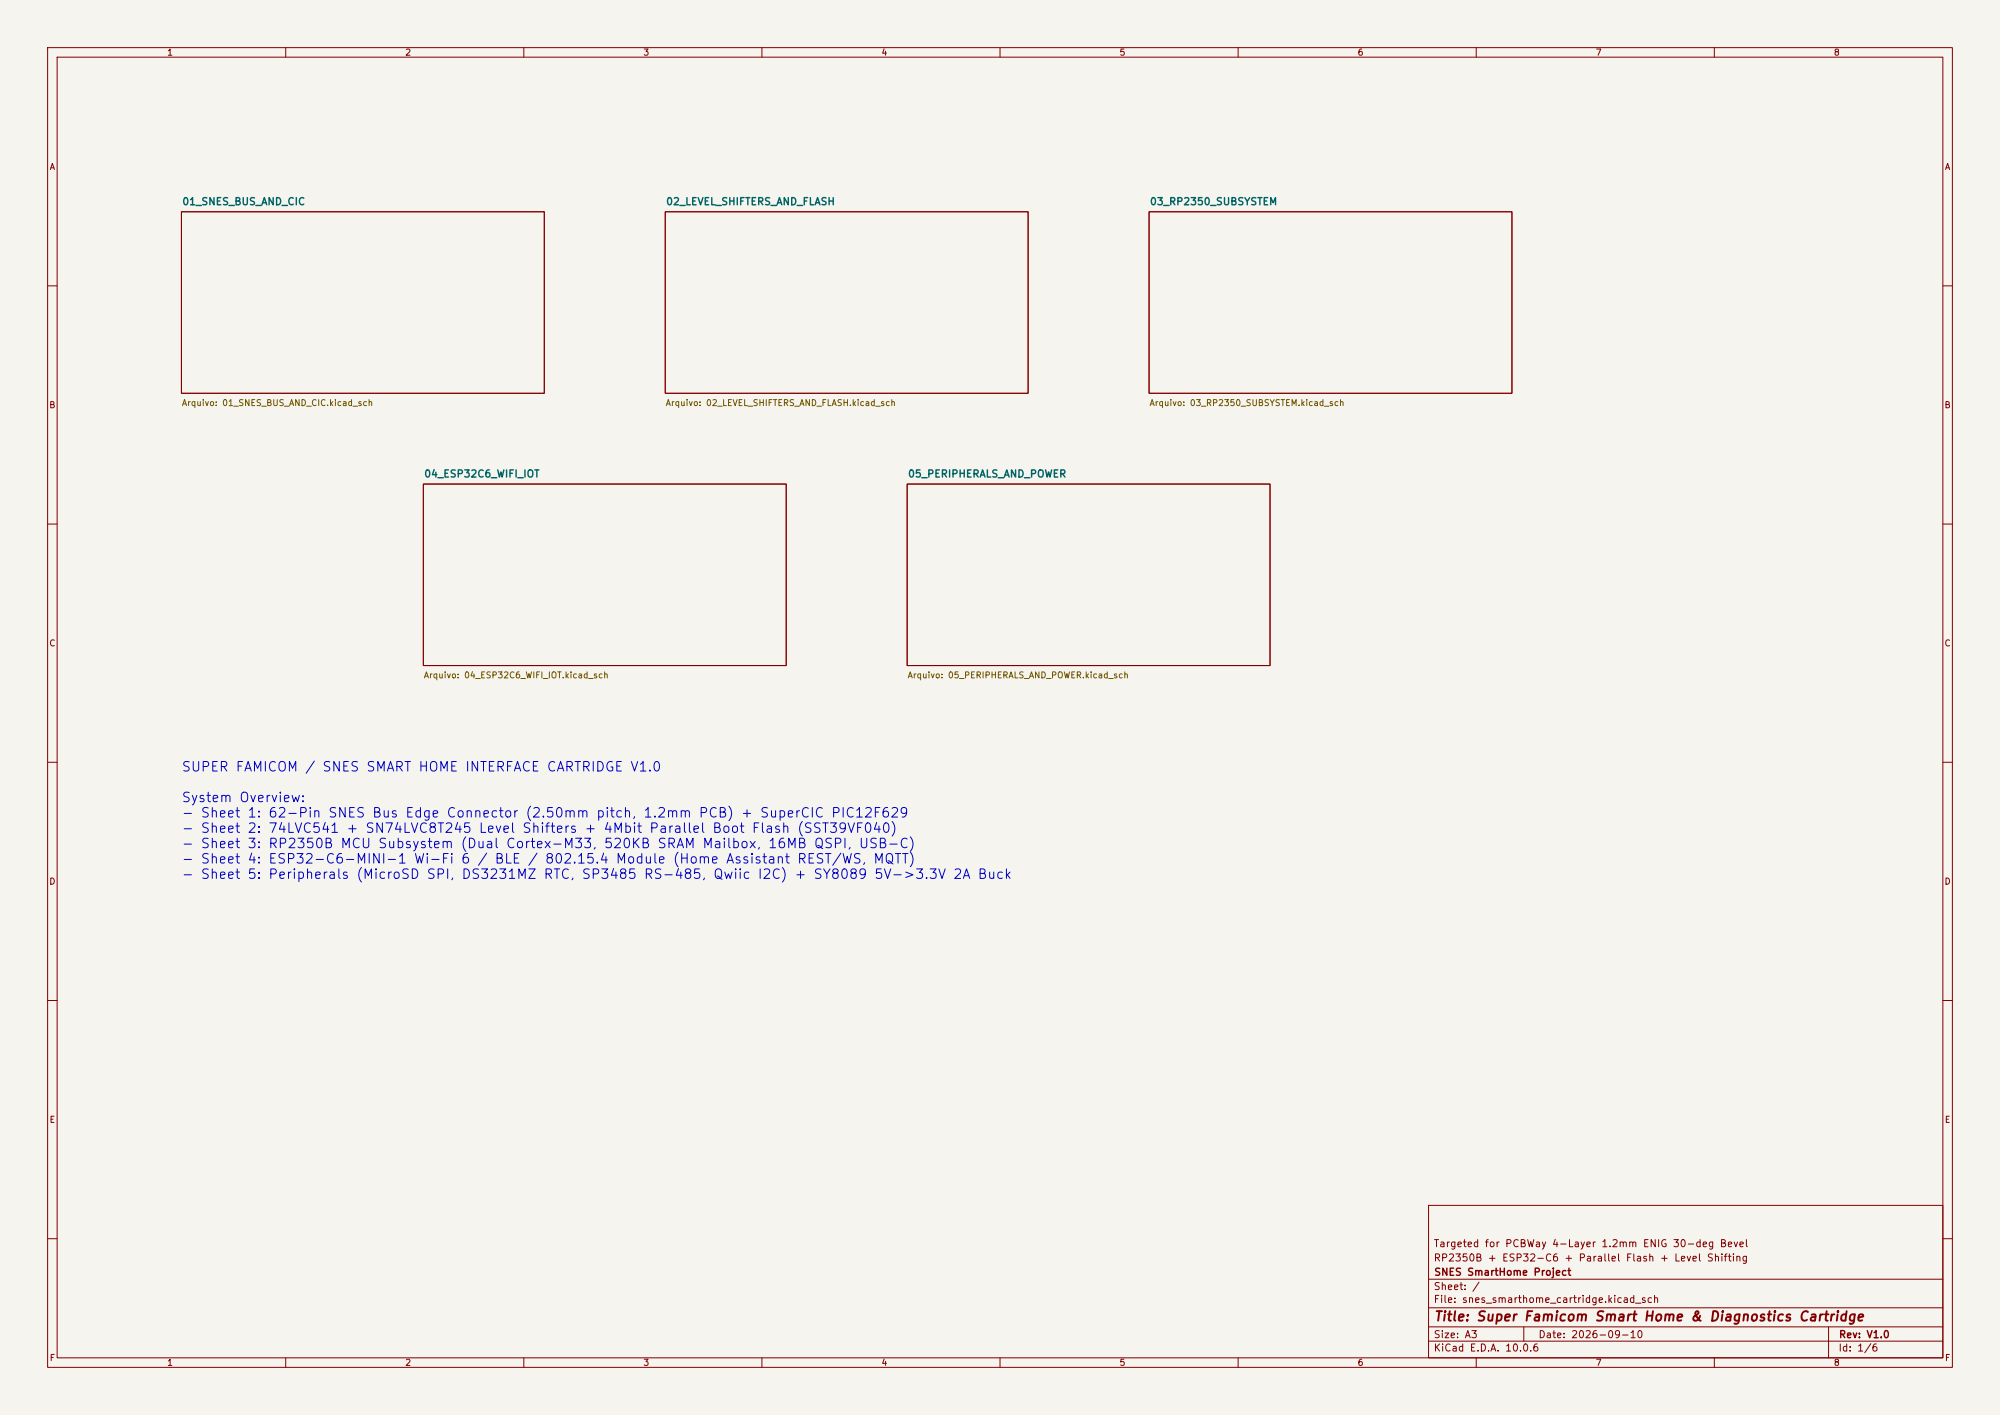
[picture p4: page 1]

Arquivo: 05_PERIPHERALS_AND_POWER.kicad_sch SUPER FAMICOM / SNES SMART HOME INTERFACE CARTRIDGE V1.0

System Overview: - Sheet 1: 62-Pin SNES Bus Edge Connector (2.50mm pitch, 1.2mm PCB) + SuperCIC PIC12F629 - Sheet 2: 74LVC541 + SN74LVC8T245 Level Shifters + 4Mbit Parallel Boot Flash (SST39VF040) - Sheet 3: RP2350B MCU Subsystem (Dual Cortex-M33, 520KB SRAM Mailbox, 16MB QSPI, USB-C) - Sheet 4: ESP32-C6-MINI-1 Wi-Fi 6 / BLE / 802.15.4 Module (Home Assistant REST/WS, MQTT) - Sheet 5: Peripherals (MicroSD SPI, DS3231MZ RTC, SP3485 RS-485, Qwiic I2C) + SY8089 5V->3.3V 2A Buck

Targeted for PCBWay 4-Layer 1.2mm ENIG 30-deg Bevel
RP2350B + ESP32-C6 + Parallel Flash + Level Shifting
SNES SmartHome Project
Sheet: /
File: snes_smarthome_cartridge.kicad_sch
Title: Super Famicom Smart Home & Diagnostics Cartridge

Size: A3 | Rev: V1.0 | F Date: 2026-09-10
KiCad E.D.A. 10.0.6 | Id: 1/6

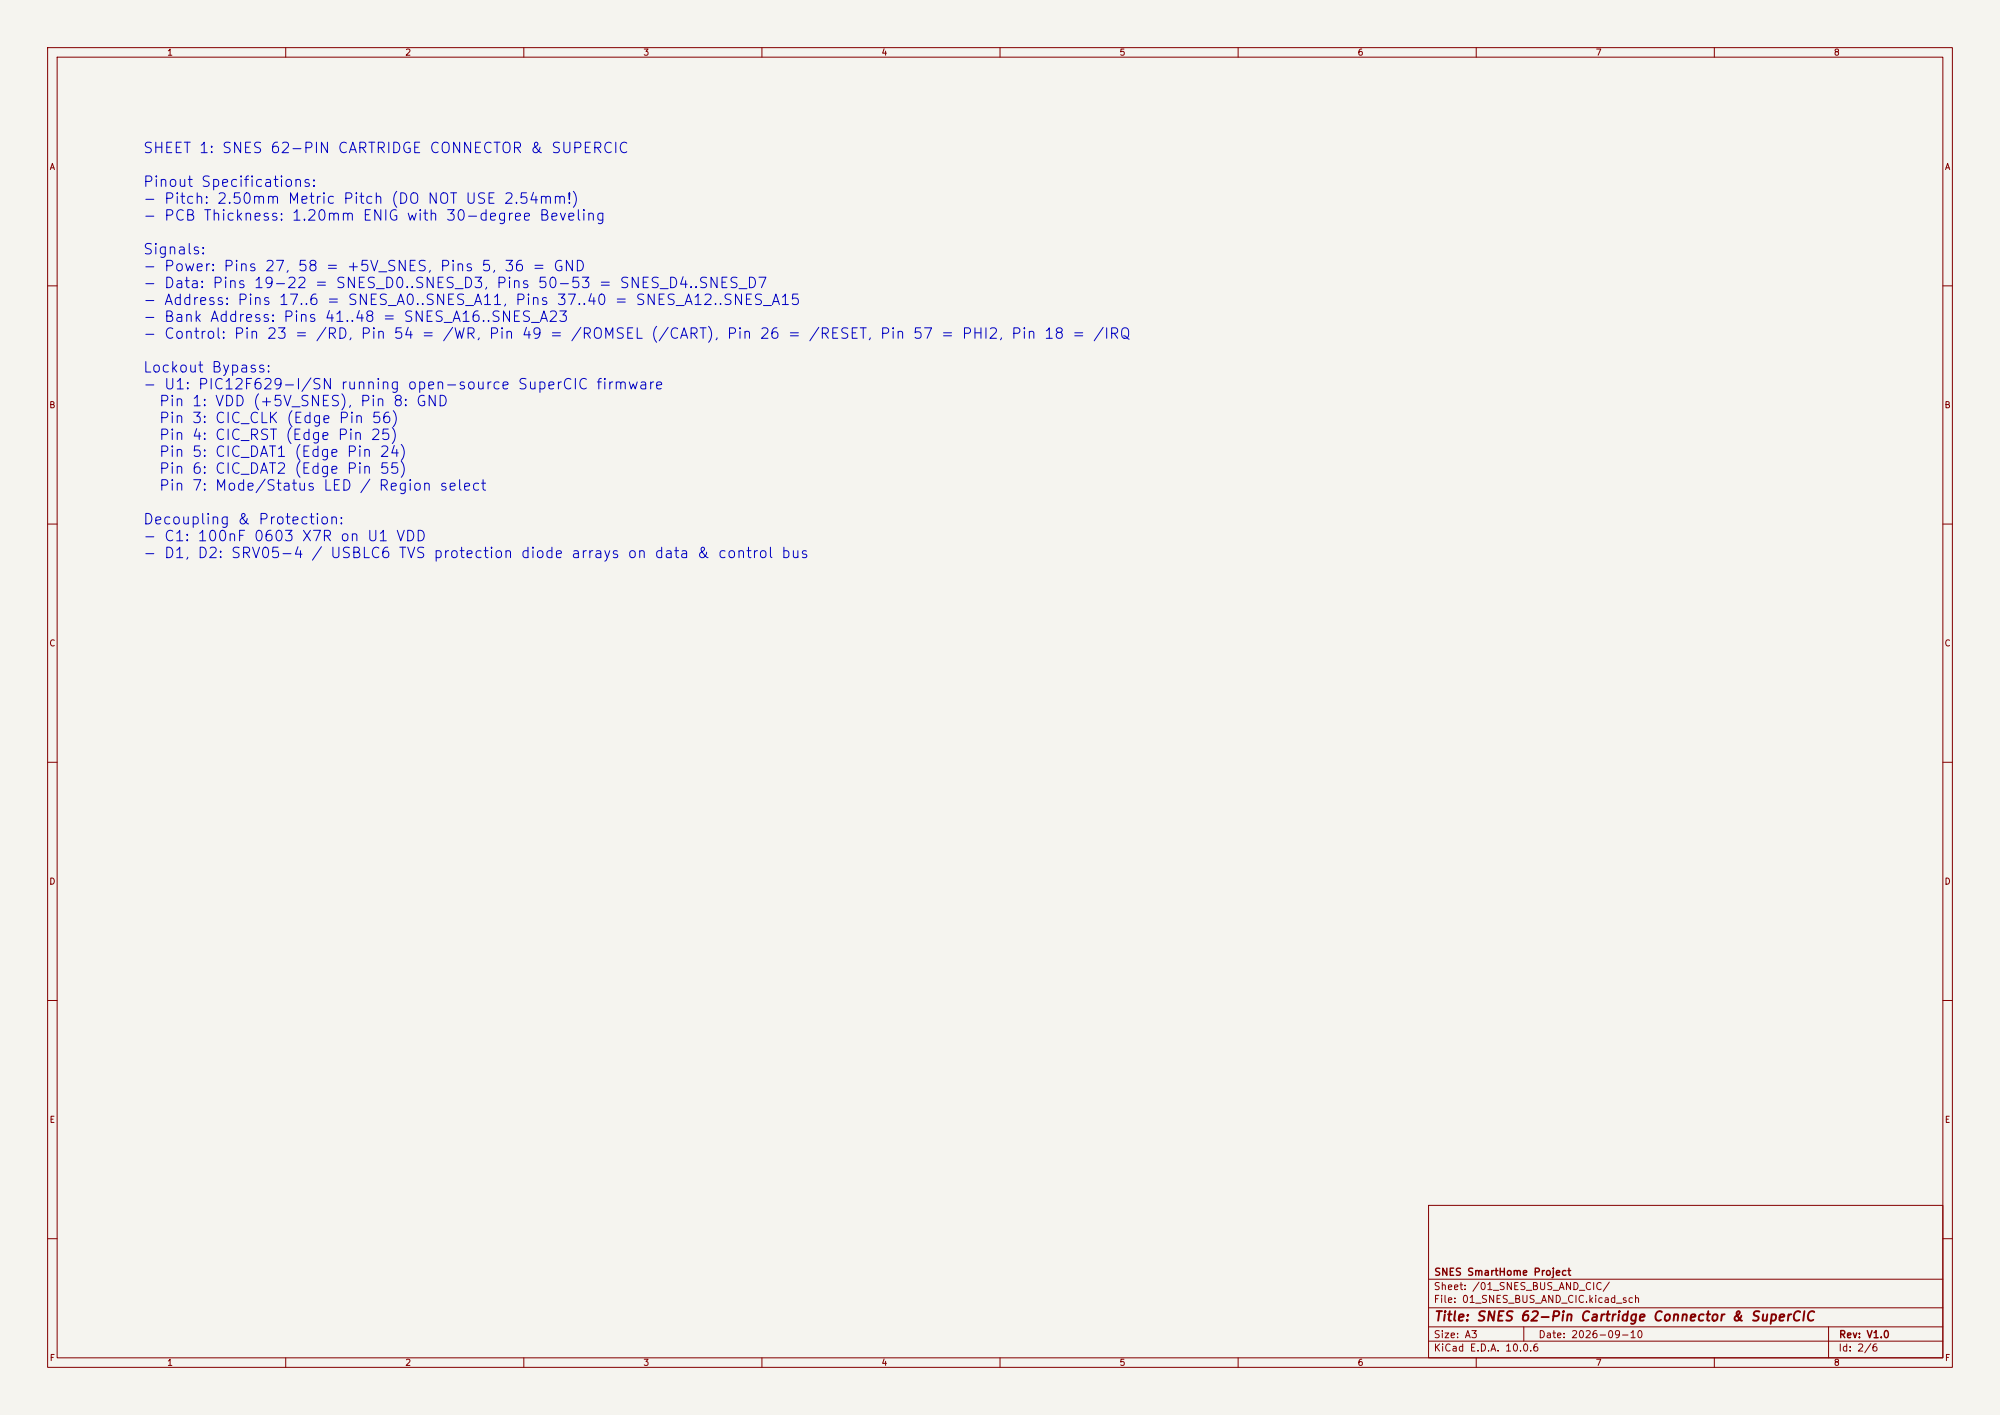
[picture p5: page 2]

SHEET 1: SNES 62-PIN CARTRIDGE CONNECTOR & SUPERCIC

Pinout Specifications: - Pitch: 2.50mm Metric Pitch (DO NOT USE 2.54mm!) - PCB Thickness: 1.20mm ENIG with 30-degree Beveling

Signals: - Power: Pins 27, 58 = +5V_SNES, Pins 5, 36 = GND - Data: Pins 19-22 = SNES_D0..SNES_D3, Pins 50-53 = SNES_D4..SNES_D7 - Address: Pins 17..6 = SNES_A0..SNES_A11, Pins 37..40 = SNES_A12..SNES_A15 - Bank Address: Pins 41..48 = SNES_A16..SNES_A23 - Control: Pin 23 = /RD, Pin 54 = /WR, Pin 49 = /ROMSEL (/CART), Pin 26 = /RESET, Pin 57 = PHI2, Pin 18 = /IRQ

Lockout Bypass: - U1: PIC12F629-I/SN running open-source SuperCIC firmware

Pin 1: VDD (+5V_SNES), Pin 8: GND
Pin 3: CIC_CLK (Edge Pin 56)
Pin 4: CIC_RST (Edge Pin 25)
Pin 5: CIC_DAT1 (Edge Pin 24)
Pin 6: CIC_DAT2 (Edge Pin 55)
Pin 7: Mode/Status LED / Region select

Decoupling & Protection: - C1: 100nF 0603 X7R on U1 VDD - D1, D2: SRV05-4 / USBLC6 TVS protection diode arrays on data & control bus

SNES SmartHome Project
Sheet: /01_SNES_BUS_AND_CIC/
File: 01_SNES_BUS_AND_CIC.kicad_sch
Title: SNES 62-Pin Cartridge Connector & SuperCIC

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
Title: ESP32-C6 Wi-Fi 6 / IoT Coprocessor

File: 04_ESP32C6_WIFI_IOT.kicad_sch

Sheet: /04_ESP32C6_WIFI_IOT/

SNES SmartHome Project

SHEET 4: ESP32-C6 WI-FI 6 / BLE / THREAD COPROCESSOR

Module: Espressif ESP32-C6-MINI-1 (or ESP32-C6-WROOM-1) - 32-bit RISC-V single-core @ 160MHz, 512KB SRAM, 4MB/8MB Flash - Wi-Fi 6 (2.4 GHz 802.11ax), Bluetooth 5 (LE), IEEE 802.15.4 (Thread/Zigbee) - Built-in certified PCB antenna (placed at the top edge of cartridge with keepout)

Role in SNES Smart Home: - Connects to local Wi-Fi and establishes Home Assistant session - Handles TLS encryption, JSON / WebSocket / REST parsing, or MQTT - Translates Home Assistant states into compact binary protocol (SH 01 + CRC16) - Pushes snapshot to RP2350 mailbox via high-speed SPI / UART - Receives command packets from RP2350 and dispatches HA service calls

Interface to RP2350: - SPI: ESP_MOSI (GPIO19), ESP_MISO (GPIO20), ESP_SCK (GPIO21), ESP_CS (GPIO18) - UART: ESP_TX (GPIO16) -> RP2350_RX, ESP_RX (GPIO17) <- RP2350_TX - Handshake IRQ: ESP_INT (GPIO22) to alert RP2350 of new states

Power & Decoupling: - 3.3V with 10uF ceramic + 100nF ceramic + bulk 47uF tantalum nearby - CHIP_PU with 10k pullup and 1uF delay capacitor for clean power-on reset - Tactile buttons: BOOT (GPIO9) and RESET (CHIP_PU) for firmware flashing - Onboard Status Indicator: WS2812B / SK6812MINI addressable RGB LED

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
Title: Level Shifters & Parallel Flash ROM

File: 02_LEVEL_SHIFTERS_AND_FLASH.kicad_sch

Sheet: /02_LEVEL_SHIFTERS_AND_FLASH/

SNES SmartHome Project

SHEET 2: VOLTAGE LEVEL SHIFTERS & BOOT FLASH ROM

Level Shifting Architecture (5V TTL <-> 3.3V CMOS):
1. Address & Control Bus (SNES -> Cartridge, Unidirectional 5V -> 3.3V): - U2: 74LVC541APW (TSSOP-20) for SNES_A0..SNES_A7, /RD, /WR - U3: 74LVC541APW (TSSOP-20) for SNES_A8..SNES_A15, /ROMSEL, PHI2 - Inputs are 5V tolerant when powered at 3.3V. Propagation delay: ~3.0 ns - /OE1, /OE2 tied to GND (always enabled)
2. Bidirectional Data Bus (SNES <-> Cartridge, 5V <-> 3.3V): - U4: SN74LVC8T245PWR (TSSOP-24 Dual-Supply Bus Transceiver) - VCCA = +5V_SNES, VCCB = +3.3V - Port A = SNES_D0..SNES_D7, Port B = BUS_D0..BUS_D7 - DIR controlled by SNES_/RD: LOW = Read (B -> A), HIGH = Write (A -> B) - /OE controlled by Cartridge Address Decoder Logic (Active on /ROMSEL or SRAM/Mailbox select)
3. Boot Flash ROM (Parallel NOR Flash): - U5: SST39VF040-70-4C-WHE (512K x 8, TSOP-32, 70ns access time) - Address inputs connected to buffered 3.3V address bus (BUS_A0..BUS_A18) - Data outputs connected to buffered 3.3V data bus (BUS_D0..BUS_D7) - /CE connected to /ROMSEL_3V3 - /OE connected to /RD_3V3 - /WE pulled to 3.3V via 10k resistor (hardware write protected, jumperable for in-system update)

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
Title: Peripherals (MicroSD, RTC, RS-485, I2C) & Power

File: 05_PERIPHERALS_AND_POWER.kicad_sch

Sheet: /05_PERIPHERALS_AND_POWER/

SNES SmartHome Project

SHEET 5: PERIPHERALS (MICROSD, RTC, RS-485, I2C) & 5V->3.3V BUCK

1. Power Supply Subsystem (High Efficiency Synchronous Buck): - Input: +5V_SNES from cartridge edge (pins 27, 58) - Reverse polarity / overcurrent protection: SS34 Schottky diode / PTC resettable fuse (1.5A) - U9: Silergy SY8089AAAC (or AP62200 / TPS62088) Synchronous Step-Down DC-DC Converter

Package: SOT-23-5, 1.5MHz switching frequency, 94% efficiency, 2.0A continuous output Inductor: L1 = 2.2uH SMD high-current power inductor (CDRH3D16 or 0805)
Feedback: R1 = 100k, R2 = 22k for calibrated 3.30V VCC rail
Input filter: 10uF 0805 X7R + 47uF low-ESR tantalum
Output filter: 22uF 0805 X7R + 47uF low-ESR tantalum
Much cooler than linear regulators (AMS1117), preserves SNES internal power brick!
2. MicroSD Card Socket: - J4: Push-Pull MicroSD connector, connected via SPI/SDIO to RP2350 - Enables logging, configuration files (wifi.txt / ha_config.json), and sound/ROM assets - 10k pullups on CS and CMD lines, dedicated 100nF + 10uF decoupling
3. High-Precision RTC (Real-Time Clock): - U10: Maxim DS3231MZ+ (SOIC-8) with integrated MEMS resonator, +-5ppm accuracy - I2C connected to RP2350 (SCL, SDA with 4.7k pullups to 3.3V) - BT1: CR1220 3V coin cell battery clip for timekeeping when console is powered off
4. RS-485 Industrial / Home Automation Bus: - U11: SP3485CN-L (SOIC-8, 3.3V half-duplex RS-485 transceiver) - Connected to RP2350 UART + direction control pin - J5: 3-pin 3.5mm screw terminal block (A, B, GND) with 120 ohm termination jumper - SM712 bidirectional TVS diode array for lightning & ESD protection on RS-485 differential lines
5. External Sensor / Display Expansion: - J6: Qwiic / STEMMA QT 4-pin 1.0mm JST-SH connector (GND, 3.3V, SDA, SCL) - Plug-and-play connection for external BME280, OLED, or radar sensors

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
Title: RP2350B MCU Subsystem & Mailbox

File: 03_RP2350_SUBSYSTEM.kicad_sch

Sheet: /03_RP2350_SUBSYSTEM/

SNES SmartHome Project

SHEET 3: RP2350B DUAL-CORE MCU SUBSYSTEM

MCU Selection: Raspberry Pi RP2350B (QFN-80) - 48 GPIOs allow dedicated bus taps and rich peripheral connectivity - Dual ARM Cortex-M33 cores @ 150MHz (overclockable to 250MHz+) - 520KB on-chip SRAM: perfectly hosts the Home Assistant Mailbox & dynamic snapshot - 12 PIO State Machines for real-time bus interception, cycle-accurate timing

Pin Allocation: - GPIO0..GPIO7: BUS_D0..BUS_D7 (Bidirectional data bus for SRAM/mailbox access) - GPIO8..GPIO23: BUS_A0..BUS_A15 (Address bus snooping & decoding) - GPIO24: BUS_/RD, GPIO25: BUS_/WR, GPIO26: BUS_/ROMSEL, GPIO27: BUS_PHI2 - GPIO28: BUS_/IRQ (Open-drain to SNES /IRQ line for instant event notification) - GPIO29..GPIO32: SPI0 to ESP32-C6 (SCK, MOSI, MISO, CS) - GPIO33, GPIO34: UART0 to ESP32-C6 (TX, RX) - GPIO35, GPIO36: I2C0 to RTC & Qwiic / STEMMA QT (SDA, SCL) - GPIO37..GPIO40: MicroSD (SPI1: SCK, MOSI, MISO, CS) - GPIO41, GPIO42: RS-485 (TX, RX, DE/RE direction) - GPIO43..GPIO47: Status LEDs, Jumper inputs

QSPI Flash Memory: - U7: Winbond W25Q128JVSIQ (16MB / 128Mbit SPI/QSPI NOR Flash, SOIC-8 208mil) - Connected to RP2350 QSPI pins with 10k pullups on CSn

Oscillator & Power: - Y1: 12.000 MHz SMD 3225 Crystal + 2x 15pF C0G capacitors - Core DVDD (1.1V): Internal regulator with 1uF + 100nF decoupling - IOVDD (3.3V): Decoupled with 100nF per VDD pin + 10uF bulk

USB-C Programming & Diagnostics: - J1: USB4110 / Type-C 16-pin connector with 5.1k pulldowns on CC1/CC2 - USBLC6-2SC6 ESD protection on D+/D- + 27 ohm series resistors - BOOTSEL & RESET tactile buttons for UF2 drag-and-drop firmware upgrades

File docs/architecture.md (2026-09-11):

# Architecture

Home Assistant is the source of truth. The first version uses `GET /api/states` on the bridge. Home Assistant's WebSocket API offers `get_states`, `get_services`, and `state_changed` subscription; V1 should migrate to WebSocket to update the UI via events.

The ROM receives `domain + features + state + name + value` and chooses the renderer. X/Y coordinates exist only as layout calculation, never as device definition.

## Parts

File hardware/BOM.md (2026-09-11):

# Super Famicom / SNES Smart Home Cartridge V1.0

## Bill of Materials (BOM) & Component Sourcing Guide

This bill of materials was sized with a focus on **global high availability** and turnkey SMT assembly at **PCBWay** or **JLCPCB**, with LCSC component codes for simplified purchasing.

---

### Main Components Table (ICs & Modules)

| Item | Designator | Component / MPN | Package | Manufacturer | LCSC Code | Qty | Function / Description | Est. Price (USD) |
|:---- |:--- |:--- |:--- |:--- |:--- |:--- |:--- |:--- |
| 1 | **U6** | **RP2350B** | QFN-80 (10x10mm) | Raspberry Pi | SC1409 / Distr. | 1 | Dual ARM Cortex-M33 @ 150MHz+, 520KB SRAM, Mailbox | ~$1.20 |
| 2 | **U7** | **W25Q128JVSIQ** | SOIC-8-208mil | Winbond | **C97521** | 1 | 16MB (128Mbit) QSPI NOR Flash for RP2350 | ~$0.65 |
| 3 | **U8** | **ESP32-C6-MINI-1-N4** | SMD Module (13.2x16.6mm) | Espressif | **C5248554** | 1 | Wi-Fi 6 + BLE 5 + Thread/Zigbee co-processor with antenna | ~$1.95 |
| 4 | **U5** | **SST39VF040-70-4C-WHE** | TSOP-32 (8x14mm) | Microchip | **C129525** | 1 | 4Mbit (512KB x 8) Parallel NOR Flash (Boot ROM) | ~$1.80 |
| 5 | **U2, U3** | **74LVC541APW** | TSSOP-20 | Nexperia / TI | **C5975** | 2 | Octal Buffer 5V -> 3.3V for address/control bus | ~$0.30 |
| 6 | **U4** | **SN74LVC8T245PWR** | TSSOP-24 | Texas Instruments | **C6207** | 1 | 8-bit Bidirectional Transceiver 5V <-> 3.3V for data bus | ~$0.45 |
| 7 | **U1** | **PIC12F629-I/SN** | SOIC-8 | Microchip | **C20967** | 1 | SuperCIC Lockout bypass universal (NTSC/PAL auto-detect) | ~$0.55 |
| 8 | **U9** | **SY8089AAAC** | SOT-23-5 | Silergy | **C28674** | 1 | Synchronous Buck Regulator 5V -> 3.3V 2.0A (efficiency >92%) | ~$0.25 |
| 9 | **U10** | **DS3231MZ+** | SOIC-8 | Analog Devices / Maxim | **C16719** | 1 | Ultra-high precision RTC (+-5ppm) with internal MEMS resonator | ~$1.60 |
| 10 | **U11** | **SP3485CN-L/TR** | SOIC-8 | MaxLinear | **C6960** | 1 | RS-485 3.3V Half-Duplex Transceiver (Modbus RTU / automation) | ~$0.40 |
| 11 | **D1, D2** | **USBLC6-2SC6** | SOT-23-6 | STMicroelectronics | **C7519** | 2 | TVS diode ESD protection for USB D+/D- and bus | ~$0.20 |
| 12 | **D3** | **WS2812B-2020** | SMD 2020 | Worldsemi | **C2890040** | 1 | Addressable RGB LED for Wi-Fi status and HA connection | ~$0.10 |
| 13 | **D4** | **SS34** | SMA / DO-214AC | MDD / Yangjie | **C46104** | 1 | 3A 40V Schottky diode reverse power protection | ~$0.08 |
| 14 | **F1** | **1206L150PR** | SMD 1206 | Littelfuse | **C70267** | 1 | PTC Resettable Fuse 1.5A 6V | ~$0.12 |

---

### Connectors & Electromechanical

| Item | Designator | Component | Description / Detail | LCSC Code | Qty | Est. Price (USD) |
|:---- |:--- |:--- |:--- |:--- |:--- |:--- |
| 15 | **P1** | **SNES Edge Fingers** | 62-pin (2x31) edge connector, **2.50 mm** pitch, ENIG 30° chamfer | Integrated in PCB | 1 | Included in PCB |
| 16 | **J1** | **TYPE-C-31-M-12** | 16-pin SMD USB-C connector for UF2 flashing and serial debug | **C165948** | 1 | ~$0.25 |
| 17 | **J4** | **TF-01A** | Push-Pull MicroSD SMD Slot | **C91145** | 1 | ~$0.30 |
| 18 | **J5** | **KF2EDG-3.5-3P** | 3.5mm 3-pin screw terminal (A, B, GND) for RS-485 bus | **C8389** | 1 | ~$0.25 |
| 19 | **J6** | **JST SH 1.0mm 4P** | Horizontal Qwiic / STEMMA QT connector (3.3V, GND, SDA, SCL) | **C145920** | 1 | ~$0.15 |
| 20 | **BT1** | **CR1220 Holder** | SMD holder for CR1220 3V coin cell (RTC backup) | **C70377** | 1 | ~$0.20 |
| 21 | **SW1..SW4** | **TS-1187A-C-A-B** | SMD tactile switches 3x4x2.0mm (BOOTSEL, RESET, ESP_BOOT, ESP_EN) | **C318884** | 4 | ~$0.05 ea. |
| 22 | **Y1** | **12.000 MHz 3225** | SMD 3225 12MHz 10ppm 18pF crystal for RP2350 | **C16280** | 1 | ~$0.15 |

---

### Critical Passives (Inductors, Capacitors, and Resistors)

| Designator | Value | Package | LCSC Code | Function |
|:--- |:--- |:--- |:--- |:--- |
| **L1** | **2.2uH / 3.0A** | SMD CD32 / 0805 | **C144887** | SY8089 Buck converter inductor |
| **C_IN1, C_OUT1**  | **47uF 10V Tantalum/Ceramic** | SMD 1206 / 3528 | **C13063**  | 5V input and 3.3V output filter |
| **C_OUT2, C_IN2**  | **22uF 10V X7R** | SMD 0805 | **C15849**  | Buck and ESP32 ceramic filter |
| **C_DEC (x12)** | **100nF (0.1uF) 16V X7R** | SMD 0402/0603 | **C14663**  | Decoupling for each IC VDD pin |
| **C_XTAL (x2)** | **15pF 50V C0G** | SMD 0402/0603 | **C1554** | 12MHz crystal load capacitors |
| **R_FB1** | **100k 1%** | SMD 0402/0603 | **C25744**  | SY8089 Buck upper feedback resistor |
| **R_FB2** | **22k 1%** | SMD 0402/0603 | **C25765**  | Lower feedback resistor (Vout = 0.6V * (1 + 100/22) = 3.32V) |
| **R_CC1, R_CC2** | **5.1k 1%** | SMD 0402/0603 | **C25905**  | USB-C CC1/CC2 pin pulldown |
| **R_USB1, R_USB2** | **27R 1%** | SMD 0402/0603 | **C25114**  | USB D+/D- series damping resistors |
| **R_PU (x8)** | **10k 5%** | SMD 0402/0603 | **C25804**  | Reset, Chip Enable, and Flash CS pullups |
| **R_I2C1, R_I2C2** | **4.7k 5%** | SMD 0402/0603 | **C25900**  | I2C bus (SDA, SCL) pullups |
| **R_TERM** | **120R 1%** | SMD 0603 | **C22787**  | RS-485 line termination resistor |

---

### Estimated Unit Cost Summary

- **ICs + Modules:** ~$8.80
- **Connectors + Mechanical + Passives:** ~$3.20
- **4-layer 1.2mm ENIG PCB (Batch 5-10 pcs):** ~$2.50 / board
- **Total estimated cost per assembled prototype:** **~$14.50 USD**

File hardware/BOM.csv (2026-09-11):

Item | Designator | Value/MPN | Package | Manufacturer | LCSC_Part_Number | Quantity | Description
1 | U6 | RP2350B | QFN-80 | Raspberry Pi | SC1409 | 1 | Dual ARM Cortex-M33 MCU 520KB SRAM
2 | U7 | W25Q128JVSIQ | SOIC-8-208mil | Winbond | C97521 | 1 | 16MB QSPI NOR Flash
3 | U8 | ESP32-C6-MINI-1-N4 | SMD Module | Espressif | C5248554 | 1 | Wi-Fi 6 + BLE 5 + Thread Module
4 | U5 | SST39VF040-70-4C-WHE | TSOP-32 | Microchip | C129525 | 1 | 4Mbit Parallel NOR Flash Boot ROM
5 | U2,U3 | 74LVC541APW | TSSOP-20 | Nexperia | C5975 | 2 | Octal 5V to 3.3V Bus Buffer
6 | U4 | SN74LVC8T245PWR | TSSOP-24 | Texas Instruments | C6207 | 1 | 8-bit Bidirectional 5V-3.3V Transceiver
7 | U1 | PIC12F629-I/SN | SOIC-8 | Microchip | C20967 | 1 | SuperCIC Universal Lockout Bypass
8 | U9 | SY8089AAAC | SOT-23-5 | Silergy | C28674 | 1 | Synchronous Buck Converter 5V to 3.3V 2A
9 | U10 | DS3231MZ+ | SOIC-8 | Maxim / ADI | C16719 | 1 | High Precision RTC with internal MEMS
10 | U11 | SP3485CN-L/TR | SOIC-8 | MaxLinear | C6960 | 1 | 3.3V RS-485 Transceiver
11 | D1,D2 | USBLC6-2SC6 | SOT-23-6 | STMicroelectronics | C7519 | 2 | TVS Diode ESD Array
12 | D3 | WS2812B-2020 | SMD-2020 | Worldsemi | C2890040 | 1 | Addressable RGB Status LED
13 | D4 | SS34 | SMA | MDD | C46104 | 1 | Schottky Diode 3A 40V Reverse Protection
14 | F1 | 1206L150PR | 1206 | Littelfuse | C70267 | 1 | PTC Resettable Fuse 1.5A
15 | J1 | TYPE-C-31-M-12 | SMD | Korean Hroparts | C165948 | 1 | USB-C 16-pin Receptacle
16 | J4 | TF-01A | SMD | Korean Hroparts | C91145 | 1 | Push-Pull MicroSD Card Socket
17 | J5 | KF2EDG-3.5-3P | 3.5mm Pitch | Cixi Gaojie | C8389 | 1 | 3-Pin Screw Terminal Block
18 | J6 | JST SH 1.0mm 4P | SMD | JST | C145920 | 1 | Qwiic / STEMMA QT I2C Connector
19 | BT1 | CR1220 Holder | SMD | MYOMY | C70377 | 1 | CR1220 Coin Cell Battery Clip
20 | SW1,SW2,SW3,SW4 | TS-1187A-C-A-B | SMD 3x4mm | Korean Hroparts | C318884 | 4 | Tactile Switch Push Button
21 | Y1 | 12.000MHz 3225 | SMD 3225 | Yangxing Tech | C16280 | 1 | Crystal 12MHz 10ppm 18pF
22 | L1 | 2.2uH 3A | SMD 0805/CD32 | Sunlord | C144887 | 1 | Power Inductor for Buck Converter
23 | C1,C2 | 47uF 10V | SMD 1206 | AVX | C13063 | 2 | Bulk Filter Capacitors
24 | C3,C4 | 22uF 10V X7R | SMD 0805 | Murata | C15849 | 2 | Ceramic Filter Capacitors
25 | C5-C16 | 100nF 16V X7R | SMD 0402 | Murata | C14663 | 12 | Decoupling Capacitors
26 | C17,C18 | 15pF 50V C0G | SMD 0402 | Murata | C1554 | 2 | Crystal Load Capacitors
27 | R1 | 100k 1% | SMD 0402 | Uniroyal | C25744 | 1 | Buck Feedback Upper Resistor
28 | R2 | 22k 1% | SMD 0402 | Uniroyal | C25765 | 1 | Buck Feedback Lower Resistor
29 | R3,R4 | 5.1k 1% | SMD 0402 | Uniroyal | C25905 | 2 | USB-C CC Pulldown Resistors
30 | R5,R6 | 27R 1% | SMD 0402 | Uniroyal | C25114 | 2 | USB D+/D- Damping Resistors
31 | R7-R14 | 10k 5% | SMD 0402 | Uniroyal | C25804 | 8 | General Pullup Resistors
32 | R15,R16 | 4.7k 5% | SMD 0402 | Uniroyal | C25900 | 2 | I2C Pullup Resistors
33 | R17 | 120R 1% | SMD 0603 | Uniroyal | C22787 | 1 | RS-485 Bus Termination Resistor

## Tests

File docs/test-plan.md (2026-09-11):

# Test Plan V0.2

## Home Assistant + bridge

1. `docker compose up -d homeassistant`
2. Open `http://127.0.0.1:8123` and complete the onboarding.
3. Create a Long-Lived Access Token in Home Assistant.
4. In the shell: `export HA_TOKEN='...'`
5. `docker compose up -d bridge`
6. `curl http://127.0.0.1:8790/entities`
7. `curl http://127.0.0.1:8790/health`

The result should contain only the entities that Home Assistant knows and that the bridge supports. The official Home Assistant documentation exposes `/api/states` for current states and WebSocket at `/api/websocket` for `get_states`, `get_services`, and `state_changed`.

## Test command

After checking the `entity_id` of the light:

```bash
curl -X POST http://127.0.0.1:8790/command \
  -H 'Content-Type: application/json' \
  -d '{"entity_id":"light.sala_light","action":"off"}'
```

For the door:

```bash
curl -X POST http://127.0.0.1:8790/command \
  -H 'Content-Type: application/json' \
  -d '{"entity_id":"cover.garagem_door","action":"open"}'
```

The exact names may vary depending on the `entity_id` generated by Home Assistant; use `/entities` as the source of truth.

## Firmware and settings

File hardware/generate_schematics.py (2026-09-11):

#!/usr/bin/env python3
"""
Generate COMPLETE KiCad 10 schematics for the SNES SmartHome cartridge.

Creates 6 schematic files:
  snes_smarthome_cartridge.kicad_sch  (root with hierarchical sheet boxes + pins)
  01_SNES_BUS_AND_CIC.kicad_sch       (SNES 62-pin connector + SuperCIC)
  02_LEVEL_SHIFTERS_AND_FLASH.kicad_sch (74LVC541 + 74LVC8T245 + SST39VF040)
  03_RP2350_SUBSYSTEM.kicad_sch       (RP2350B MCU + QSPI Flash + USB-C)
  04_ESP32C6_WIFI_IOT.kicad_sch       (ESP32-C6-MINI-1 + WS2812B)
  05_PERIPHERALS_AND_POWER.kicad_sch   (Buck + RTC + RS-485 + MicroSD + connectors)

KiCad 10 format: version 20250114, generator "eeschema", generator_version "10.0"
Component count: 62 (matches BOM.md exactly)

Libraries used:
  Standard:  Device:C, Device:R, Device:L, Device:Crystal, Device:SW_Push,
             Device:D_Schottky, Device:Polyfuse,
             MCU_Microchip_PIC:PIC12F629, Logic_74xx:74LVC541A,
             Memory_Flash:W25Q128, Timer_RTC:DS3231,
             Interface_UART:MAX3485, Connector:USB_C_Receptacle_16P,
             Connector:Conn_01x03, Connector:Conn_01x04
  Custom:   Custom:RP2350B, Custom:ESP32-C6-MINI-1, Custom:SY8089,
             Custom:SNES_62PIN, Custom:SST39VF040, Custom:USBLC6-2SC6,
             Custom:WS2812B
"""

import os
import sys
import uuid
import re
from collections import Counter

HW_DIR = os.path.dirname(os.path.abspath(__file__))

# ══════════════════════════════════════════════════════════════════════════════
#  UUID generator
# ══════════════════════════════════════════════════════════════════════════════
def uid():
    return str(uuid.uuid4())


# ══════════════════════════════════════════════════════════════════════════════
#  Validation helpers
# ══════════════════════════════════════════════════════════════════════════════

def validate_parentheses(content, filename):
    """Check that open and close parentheses are balanced."""
    opens = content.count('(')
    closes = content.count(')')
    if opens != closes:
        print(f"  FAIL: {filename} has unbalanced parentheses: ({opens} open, {closes} close)")
        return False
    print(f"  OK: {filename} parentheses balanced ({opens} pairs)")
    return True


def count_components(content):
    """Count placed component instances (symbol blocks with lib_id)."""
    return len(re.findall(r'^\t\(lib_id ', content, re.MULTILINE))


def count_hierarchical_labels(content):
    """Count hierarchical_label blocks."""
    return len(re.findall(r'^\t\(hierarchical_label ', content, re.MULTILINE))


# ══════════════════════════════════════════════════════════════════════════════
#  KiCad 10 S-expression helpers
# ══════════════════════════════════════════════════════════════════════════════

def sym(lib_id, ref, value, footprint, lcsc, x, y, rotation=0, unit=1):
    ref_y = y + 2.54
    val_y = y - 2.54
    return (
        f'\t(symbol\n'
        f'\t\t(lib_id "{lib_id}")\n'
        f'\t\t(at {x} {y} {rotation})\n'
        f'\t\t(unit {unit})\n'
        f'\t\t(exclude_from_sim no)\n'
        f'\t\t(in_bom yes)\n'
        f'\t\t(on_board yes)\n'
        f'\t\t(dnp no)\n'
        f'\t\t(uuid "{uid()}")\n'
        f'\t\t(property "Reference" "{ref}" (at {x} {ref_y} 0)\n'
        f'\t\t\t(effects (font (size 1.27 1.27)))\n'
        f'\t\t)\n'
        f'\t\t(property "Value" "{value}" (at {x} {val_y} 0)\n'
        f'\t\t\t(effects (font (size 1.27 1.27)))\n'
        f'\t\t)\n'
        f'\t\t(property "Footprint" "{footprint}" (at {x} {y} 0)\n'
        f'\t\t\t(effects (font (size 1.27 1.27)) hide)\n'
        f'\t\t)\n'
        f'\t\t(property "LCSC" "{lcsc}" (at {x} {y} 0)\n'
        f'\t\t\t(effects (font (size 1.27 1.27)) hide)\n'
        f'\t\t)\n'
        f'\t)\n'
    )


def wire(x1, y1, x2, y2):
    return (
        f'\t(wire (pts (xy {x1} {y1}) (xy {x2} {y2}))\n'
        f'\t\t(stroke (width 0) (type default))\n'
        f'\t\t(uuid "{uid()}")\n'
        f'\t)\n'
    )


def netlabel(name, x, y, rotation=0):
    return (
        f'\t(label "{name}"\n'
        f'\t\t(at {x} {y} {rotation})\n'
        f'\t\t(effects (font (size 1.27 1.27)))\n'
        f'\t\t(uuid "{uid()}")\n'
        f'\t)\n'
    )


def pwr_sym(name, x, y, rotation=0):
    return (
        f'\t(power_port "{name}"\n'
        f'\t\t(at {x} {y} {rotation})\n'
        f'\t\t(effects (font (size 1.27 1.27)))\n'
        f'\t\t(uuid "{uid()}")\n'
        f'\t\t(property "Intersheetrefs" "${{INTERSHEET_REFS}}" (at 0 0 0) (effects (font (size 1.27 1.27)) hide))\n'
        f'\t)\n'
    )


def hlabel(name, shape, x, y, rotation=180):
    return (
        f'\t(hierarchical_label "{name}"\n'
        f'\t\t(shape {shape})\n'
        f'\t\t(at {x} {y} {rotation})\n'
        f'\t\t(effects (font (size 1.27 1.27)))\n'
        f'\t\t(uuid "{uid()}")\n'
        f'\t)\n'
    )


def hpin(name, direction, x, y, rotation=0):
    return (
        f'\t(pin "{name}"\n'
        f'\t\t(direction {direction})\n'
        f'\t\t(at {x} {y} {rotation})\n'
        f'\t\t(effects (font (size 1.27 1.27)))\n'
        f'\t\t(uuid "{uid()}")\n'
        f'\t)\n'
    )


def text_block(text, x, y, size=2.0):
    escaped = text.replace('\\', '\\\\').replace('"', '\\"')
    return (
        f'\t(text "{escaped}"\n'
        f'\t\t(at {x} {y} 0)\n'
        f'\t\t(effects (font (size {size} {size})) (justify left top))\n'
        f'\t\t(uuid "{uid()}")\n'
        f'\t)\n'
    )


def no_connect(x, y):
    return f'\t(no_connect (at {x} {y}) (uuid "{uid()}"))\n'


def _pin(name, number, ptype, x, y, angle, length=2.54):
    return (
        f'\t\t\t(pin {ptype} line\n'
        f'\t\t\t\t(at {x} {y} {angle})\n'
        f'\t\t\t\t(length {length})\n'
        f'\t\t\t\t(name "{name}"\n'
        f'\t\t\t\t\t(effects (font (size 1.27 1.27)))\n'
        f'\t\t\t\t)\n'
        f'\t\t\t\t(number "{number}"\n'
        f'\t\t\t\t\t(effects (font (size 1.27 1.27)))\n'
        f'\t\t\t\t)\n'
        f'\t\t\t)\n'
    )

# ══════════════════════════════════════════════════════════════════════════════
#  Standard KiCad library symbol definitions (minimal, for self-containment)
# ══════════════════════════════════════════════════════════════════════════════

def _device_c_symbol():
    return (
        '\t\t(symbol "Device:C"\n'
        '\t\t\t(pin_names (offset 0.254))\n'
        '\t\t\t(in_bom yes)\n'
        '\t\t\t(on_board yes)\n'
        '\t\t\t(property "Reference" "C" (at 0.635 2.54 0)\n'
        '\t\t\t\t(effects (font (size 1.27 1.27)))\n'
        '\t\t\t)\n'
        '\t\t\t(property "Value" "C" (at 0.635 -2.54 0)\n'
        '\t\t\t\t(effects (font (size 1.27 1.27)))\n'
        '\t\t\t)\n'
        '\t\t\t(symbol "C_0_1"\n'
        '\t\t\t\t(polyline (pts (xy -1.524 0.508) (xy 1.524 0.508))\n'
        '\t\t\t\t\t(stroke (width 0.3048) (type default))\n'
        '\t\t\t\t)\n'
        '\t\t\t\t(polyline (pts (xy -1.524 -0.508) (xy 1.524 -0.508))\n'
        '\t\t\t\t\t(stroke (width 0.3048) (type default))\n'
        '\t\t\t\t)\n'
        '\t\t\t)\n'
        '\t\t\t(symbol "C_1_1"\n'
        '\t\t\t\t(pin passive line\n'
        '\t\t\t\t\t(at 0 3.81 270)\n'
        '\t\t\t\t\t(length 1.27)\n'
        '\t\t\t\t\t(name "~" (effects (font (size 1.27 1.27))))\n'
        '\t\t\t\t\t(number "1" (effects (font (size 1.27 1.27))))\n'
        '\t\t\t\t)\n'
        '\t\t\t\t(pin passive line\n'
        '\t\t\t\t\t(at 0 -3.81 90)\n'
        '\t\t\t\t\t(length 1.27)\n'
        '\t\t\t\t\t(name "~" (effects (font (size 1.27 1.27))))\n'
        '\t\t\t\t\t(number "2" (effects (font (size 1.27 1.27))))\n'
        '\t\t\t\t)\n'
        '\t\t\t)\n'
        '\t\t)\n'
    )


def _device_r_symbol():
    return (
        '\t\t(symbol "Device:R"\n'
        '\t\t\t(pin_names (offset 0))\n'
        '\t\t\t(in_bom yes)\n'
        '\t\t\t(on_board yes)\n'
        '\t\t\t(property "Reference" "R" (at 2.032 0 90)\n'
        '\t\t\t\t(effects (font (size 1.27 1.27)))\n'
        '\t\t\t)\n'
        '\t\t\t(property "Value" "R" (at 0 0 90)\n'
        '\t\t\t\t(effects (font (size 1.27 1.27)))\n'
        '\t\t\t)\n'
        '\t\t\t(symbol "R_0_1"\n'
        '\t\t\t\t(rectangle (start -1.016 2.54) (end 1.016 -2.54)\n'
        '\t\t\t\t\t(stroke (width 0.254) (type default))\n'
        '\t\t\t\t\t(fill (type none))\n'
        '\t\t\t\t)\n'
        '\t\t\t)\n'
        '\t\t\t(symbol "R_1_1"\n'
        '\t\t\t\t(pin passive line\n'
        '\t\t\t\t\t(at 0 3.81 270)\n'
        '\t\t\t\t\t(length 1.27)\n'
        '\t\t\t\t\t(name "~" (effects (font (size 1.27 1.27))))\n'
        '\t\t\t\t\t(number "1" (effects (font (size 1.27 1.27))))\n'
        '\t\t\t\t)\n'
        '\t\t\t\t(pin passive line\n'
        '\t\t\t\t\t(at 0 -3.81 90)\n'
        '\t\t\t\t\t(length 1.27)\n'
        '\t\t\t\t\t(name "~" (effects (font (size 1.27 1.27))))\n'
        '\t\t\t\t\t(number "2" (effects (font (size 1.27 1.27))))\n'
        '\t\t\t\t)\n'
        '\t\t\t)\n'
        '\t\t)\n'
    )


def _device_crystal_symbol():
    return (
        '\t\t(symbol "Device:Crystal"\n'
        '\t\t\t(pin_names (offset 0))\n'
        '\t\t\t(in_bom yes)\n'
        '\t\t\t(on_board yes)\n'
        '\t\t\t(property "Reference" "Y" (at 0 3.81 0)\n'
        '\t\t\t\t(effects (font (size 1.27 1.27)))\n'
        '\t\t\t)\n'
        '\t\t\t(property "Value" "Crystal" (at 0 -3.81 0)\n'
        '\t\t\t\t(effects (font (size 1.27 1.27)))\n'
        '\t\t\t)\n'
        '\t\t\t(symbol "Crystal_0_1"\n'
        '\t\t\t\t(polyline (pts (xy -1.524 1.524) (xy -1.524 -1.524))\n'
        '\t\t\t\t\t(stroke (width 0.3048) (type default))\n'
        '\t\t\t\t)\n'
        '\t\t\t\t(polyline (pts (xy 1.524 1.524) (xy 1.524 -1.524))\n'
        '\t\t\t\t\t(stroke (width 0.3048) (type default))\n'
        '\t\t\t\t)\n'
        '\t\t\t\t(rectangle (start -0.762 2.286) (end 0.762 -2.286)\n'
        '\t\t\t\t\t(stroke (width 0.254) (type default))\n'
        '\t\t\t\t\t(fill (type none))\n'
        '\t\t\t\t)\n'
        '\t\t\t)\n'
        '\t\t\t(symbol "Crystal_1_1"\n'
        '\t\t\t\t(pin passive line\n'
        '\t\t\t\t\t(at 0 5.08 270)\n'
        '\t\t\t\t\t(length 2.54)\n'
        '\t\t\t\t\t(name "~" (effects (font (size 1.27 1.27))))\n'
        '\t\t\t\t\t(number "1" (effects (font (size 1.27 1.27))))\n'
        '\t\t\t\t)\n'
        '\t\t\t\t(pin passive line\n'
        '\t\t\t\t\t(at 0 -5.08 90)\n'
        '\t\t\t\t\t(length 2.54)\n'
        '\t\t\t\t\t(name "~" (effects (font (size 1.27 1.27))))\n'
        '\t\t\t\t\t(number "2" (effects (font (size 1.27 1.27))))\n'
        '\t\t\t\t)\n'
        '\t\t\t)\n'
        '\t\t)\n'
    )


def _device_sw_push_symbol():
    return (
        '\t\t(symbol "Device:SW_Push"\n'
        '\t\t\t(pin_names (offset 0))\n'
        '\t\t\t(in_bom yes)\n'
        '\t\t\t(on_board yes)\n'
        '\t\t\t(property "Reference" "SW" (at 0 2.54 0)\n'
        '\t\t\t\t(effects (font (size 1.27 1.27)))\n'
        '\t\t\t)\n'
        '\t\t\t(property "Value" "SW_Push" (at 0 -2.54 0)\n'
        '\t\t\t\t(effects (font (size 1.27 1.27)))\n'
        '\t\t\t)\n'
        '\t\t\t(symbol "SW_Push_0_1"\n'
        '\t\t\t\t(circle (center -1.778 0) (radius 0.508)\n'
        '\t\t\t\t\t(stroke (width 0) (type default))\n'
        '\t\t\t\t\t(fill (type none))\n'
        '\t\t\t\t)\n'
        '\t\t\t\t(circle (center 1.778 0) (radius 0.508)\n'
        '\t\t\t\t\t(stroke (width 0) (type default))\n'
        '\t\t\t\t\t(fill (type none))\n'
        '\t\t\t\t)\n'
        '\t\t\t)\n'
        '\t\t\t(symbol "SW_Push_1_1"\n'
        '\t\t\t\t(pin passive line\n'
        '\t\t\t\t\t(at 0 5.08 270)\n'
        '\t\t\t\t\t(length 2.54)\n'
        '\t\t\t\t\t(name "~" (effects (font (size 1.27 1.27))))\n'
        '\t\t\t\t\t(number "1" (effects (font (size 1.27 1.27))))\n'
        '\t\t\t\t)\n'
        '\t\t\t\t(pin passive line\n'
        '\t\t\t\t\t(at 0 -5.08 90)\n'
        '\t\t\t\t\t(length 2.54)\n'
        '\t\t\t\t\t(name "~" (effects (font (size 1.27 1.27))))\n'
        '\t\t\t\t\t(number "2" (effects (font (size 1.27 1.27))))\n'
        '\t\t\t\t)\n'
        '\t\t\t)\n'
        '\t\t)\n'
    )


def _device_l_symbol():
    return (
        '\t\t(symbol "Device:L"\n'
        '\t\t\t(pin_names (offset 0))\n'
        '\t\t\t(in_bom yes)\n'
        '\t\t\t(on_board yes)\n'
        '\t\t\t(property "Reference" "L" (at 2.54 0 90)\n'
        '\t\t\t\t(effects (font (size 1.27 1.27)))\n'
        '\t\t\t)\n'
        '\t\t\t(property "Value" "L" (at 0 0 90)\n'
        '\t\t\t\t(effects (font (size 1.27 1.27)))\n'
        '\t\t\t)\n'
        '\t\t\t(symbol "L_0_1"\n'
        '\t\t\t\t(arc (start 0 -2.54) (mid 1.27 0) (end 0 2.54)\n'
        '\t\t\t\t\t(stroke (width 0.3048) (type default))\n'
        '\t\t\t\t)\n'
        '\t\t\t\t(arc (start 0 -2.54) (mid -1.27 0) (end 0 2.54)\n'
        '\t\t\t\t\t(stroke (width 0.3048) (type default))\n'
        '\t\t\t\t)\n'
        '\t\t\t)\n'
        '\t\t\t(symbol "L_1_1"\n'
        '\t\t\t\t(pin passive line\n'
        '\t\t\t\t\t(at 0 5.08 270)\n'
        '\t\t\t\t\t(length 2.54)\n'
        '\t\t\t\t\t(name "~" (effects (font (size 1.27 1.27))))\n'
        '\t\t\t\t\t(number "1" (effects (font (size 1.27 1.27))))\n'
        '\t\t\t\t)\n'
        '\t\t\t\t(pin passive line\n'
        '\t\t\t\t\t(at 0 -5.08 90)\n'
        '\t\t\t\t\t(length 2.54)\n'
        '\t\t\t\t\t(name "~" (effects (font (size 1.27 1.27))))\n'
        '\t\t\t\t\t(number "2" (effects (font (size 1.27 1.27))))\n'
        '\t\t\t\t)\n'
        '\t\t\t)\n'
        '\t\t)\n'
    )


def _device_d_schottky_symbol():
    """Device:D_Schottky — Schottky diode (2-pin)."""
    return (
        '\t\t(symbol "Device:D_Schottky"\n'
        '\t\t\t(pin_names (offset 0.254))\n'
        '\t\t\t(in_bom yes)\n'
        '\t\t\t(on_board yes)\n'
        '\t\t\t(property "Reference" "D" (at 0 2.54 0)\n'
        '\t\t\t\t(effects (font (size 1.27 1.27)))\n'
        '\t\t\t)\n'
        '\t\t\t(property "Value" "D_Schottky" (at 0 -2.54 0)\n'
        '\t\t\t\t(effects (font (size 1.27 1.27)))\n'
        '\t\t\t)\n'
        '\t\t\t(symbol "D_Schottky_0_1"\n'
        '\t\t\t\t(polyline (pts (xy -1.27 1.27) (xy -1.27 -1.27) (xy 1.27 0) (xy -1.27 1.27))\n'
        '\t\t\t\t\t(stroke (width 0.254) (type default))\n'
        '\t\t\t\t\t(fill (type none))\n'
        '\t\t\t\t)\n'
        '\t\t\t\t(polyline (pts (xy 1.27 1.27) (xy 1.27 -1.27) (xy 1.8034 -1.27))\n'
        '\t\t\t\t\t(stroke (width 0.254) (type default))\n'
        '\t\t\t\t)\n'
        '\t\t\t)\n'
        '\t\t\t(symbol "D_Schottky_1_1"\n'
        '\t\t\t\t(pin passive line\n'
        '\t\t\t\t\t(at 0 3.81 270)\n'
        '\t\t\t\t\t(length 1.27)\n'
        '\t\t\t\t\t(name "K" (effects (font (size 1.27 1.27))))\n'
        '\t\t\t\t\t(number "1" (effects (font (size 1.27 1.27))))\n'
        '\t\t\t\t)\n'
        '\t\t\t\t(pin passive line\n'
        '\t\t\t\t\t(at 0 -3.81 90)\n'
        '\t\t\t\t\t(length 1.27)\n'
        '\t\t\t\t\t(name "A" (effects (font (size 1.27 1.27))))\n'
        '\t\t\t\t\t(number "2" (effects (font (size 1.27 1.27))))\n'
        '\t\t\t\t)\n'
        '\t\t\t)\n'
        '\t\t)\n'
    )


def _device_polyfuse_symbol():
    return (
        '\t\t(symbol "Device:Polyfuse"\n'
        '\t\t\t(pin_names (offset 0))\n'
        '\t\t\t(in_bom yes)\n'
        '\t\t\t(on_board yes)\n'
        '\t\t\t(property "Reference" "F" (at 2.54 0 90)\n'
        '\t\t\t\t(effects (font (size 1.27 1.27)))\n'
        '\t\t\t)\n'
        '\t\t\t(property "Value" "Polyfuse" (at 0 0 90)\n'
        '\t\t\t\t(effects (font (size 1.27 1.27)))\n'
        '\t\t\t)\n'
        '\t\t\t(symbol "Polyfuse_0_1"\n'
        '\t\t\t\t(polyline (pts (xy 0 -2.54) (xy 0 -1.27) (xy 1.27 -0.635) (xy 1.27 0.635) (xy 0 1.27) (xy 0 2.54))\n'
        '\t\t\t\t\t(stroke (width 0.3048) (type default))\n'
        '\t\t\t\t)\n'
        '\t\t\t)\n'
        '\t\t\t(symbol "Polyfuse_1_1"\n'
        '\t\t\t\t(pin passive line\n'
        '\t\t\t\t\t(at 0 5.08 270)\n'
        '\t\t\t\t\t(length 2.54)\n'
        '\t\t\t\t\t(name "~" (effects (font (size 1.27 1.27))))\n'
        '\t\t\t\t\t(number "1" (effects (font (size 1.27 1.27))))\n'
        '\t\t\t\t)\n'
        '\t\t\t\t(pin passive line\n'
        '\t\t\t\t\t(at 0 -5.08 90)\n'
        '\t\t\t\t\t(length 2.54)\n'
        '\t\t\t\t\t(name "~" (effects (font (size 1.27 1.27))))\n'
        '\t\t\t\t\t(number "2" (effects (font (size 1.27 1.27))))\n'
        '\t\t\t\t)\n'
        '\t\t\t)\n'
        '\t\t)\n'
    )


def _battery_cr1220_symbol():
    return (
        '\t\t(symbol "Battery:BatteryHolder_CR1220"\n'
        '\t\t\t(pin_names (offset 0.254))\n'
        '\t\t\t(in_bom yes)\n'
        '\t\t\t(on_board yes)\n'
        '\t\t\t(property "Reference" "BT" (at 0 3.81 0)\n'
        '\t\t\t\t(effects (font (size 1.27 1.27)))\n'
        '\t\t\t)\n'
        '\t\t\t(property "Value" "CR1220" (at 0 -3.81 0)\n'
        '\t\t\t\t(effects (font (size 1.27 1.27)))\n'
        '\t\t\t)\n'
        '\t\t\t(symbol "Battery_0_1"\n'
        '\t\t\t\t(polyline (pts (xy -2.54 -1.27) (xy 2.54 -1.27))\n'
        '\t\t\t\t\t(stroke (width 0.508) (type default))\n'
        '\t\t\t\t)\n'
        '\t\t\t\t(polyline (pts (xy -1.27 1.27) (xy 1.27 1.27))\n'
        '\t\t\t\t\t(stroke (width 0.254) (type default))\n'
        '\t\t\t\t)\n'
        '\t\t\t)\n'
        '\t\t\t(symbol "Battery_1_1"\n'
        '\t\t\t\t(pin power_in line\n'
        '\t\t\t\t\t(at 0 5.08 270)\n'
        '\t\t\t\t\t(length 2.54)\n'
        '\t\t\t\t\t(name "+" (effects (font (size 1.27 1.27))))\n'
        '\t\t\t\t\t(number "1" (effects (font (size 1.27 1.27))))\n'
        '\t\t\t\t)\n'
        '\t\t\t\t(pin power_in line\n'
        '\t\t\t\t\t(at 0 -5.08 90)\n'
        '\t\t\t\t\t(length 2.54)\n'
        '\t\t\t\t\t(name "-" (effects (font (size 1.27 1.27))))\n'
        '\t\t\t\t\t(number "2" (effects (font (size 1.27 1.27))))\n'
        '\t\t\t\t)\n'
        '\t\t\t)\n'
        '\t\t)\n'
    )

# ══════════════════════════════════════════════════════════════════════════════
#  Custom library symbol definitions (components not in standard KiCad libs)
# ══════════════════════════════════════════════════════════════════════════════

def _snes_connector_symbol():
    lines = []
    left = [
        (1, "NC"), (2, "NC"), (3, "NC"), (4, "NC"),
        (5, "GND"), (6, "SNES_A0"), (7, "SNES_A1"), (8, "SNES_A2"),
        (9, "SNES_A3"), (10, "SNES_A4"), (11, "SNES_A5"), (12, "SNES_A6"),
        (13, "SNES_A7"), (14, "SNES_A8"), (15, "SNES_A9"), (16, "SNES_A10"),
        (17, "SNES_A11"), (18, "/IRQ"), (19, "SNES_D0"), (20, "SNES_D1"),
        (21, "SNES_D2"), (22, "SNES_D3"), (23, "/RD"), (24, "CIC_DAT1"),
        (25, "CIC_RST"), (26, "/RESET"), (27, "+5V_SNES"),
        (28, "NC"), (29, "NC"), (30, "NC"), (31, "NC"),
    ]
    right = [
        (32, "NC"), (33, "NC"), (34, "NC"), (35, "NC"),
        (36, "GND"), (37, "SNES_A12"), (38, "SNES_A13"), (39, "SNES_A14"),
        (40, "SNES_A15"), (41, "SNES_A16"), (42, "SNES_A17"), (43, "SNES_A18"),
        (44, "SNES_A19"), (45, "SNES_A20"), (46, "SNES_A21"), (47, "SNES_A22"),
        (48, "SNES_A23"), (49, "/ROMSEL"), (50, "SNES_D4"), (51, "SNES_D5"),
        (52, "SNES_D6"), (53, "SNES_D7"), (54, "/WR"), (55, "CIC_DAT2"),
        (56, "CIC_CLK"), (57, "PHI2"), (58, "+5V_SNES"),
        (59, "NC"), (60, "NC"), (61, "NC"), (62, "NC"),
    ]
    y0 = -38.1
    for i, (num, name) in enumerate(left):
        py = y0 + i * 2.50
        pt = "power_in" if name in ("GND", "+5V_SNES") else "bidirectional"
        lines.append(_pin(name, str(num), pt, -30.48, py, 0, 2.54))
    for i, (num, name) in enumerate(right):
        py = y0 + i * 2.50
        pt = "power_in" if name in ("GND", "+5V_SNES") else "bidirectional"
        lines.append(_pin(name, str(num), pt, 30.48, py, 180, 2.54))
    pins = "".join(lines)
    return (
        '\t\t(symbol "Custom:SNES_62PIN"\n'
        '\t\t\t(pin_names (offset 1.016))\n'
        '\t\t\t(in_bom yes)\n'
        '\t\t\t(on_board yes)\n'
        '\t\t\t(property "Reference" "P1" (at 0 -48 0)\n'
        '\t\t\t\t(effects (font (size 1.27 1.27)))\n'
        '\t\t\t)\n'
        '\t\t\t(property "Value" "SNES_EDGE_62" (at 0 48 0)\n'
        '\t\t\t\t(effects (font (size 1.27 1.27)))\n'
        '\t\t\t)\n'
        f'{pins}'
        '\t\t)\n'
    )


def _pic12f629_symbol():
    pins = (
        _pin("VDD", "1", "power_in", 0, 10.16, 270)
        + _pin("RA5", "2", "bidirectional", -10.16, 5.08, 0)
        + _pin("RA4", "3", "bidirectional", -10.16, 2.54, 0)
        + _pin("RA3/MCLR", "4", "input", -10.16, 0, 0)
        + _pin("RA2", "5", "output", -10.16, -2.54, 0)
        + _pin("RA1", "6", "passive", -10.16, -5.08, 0)
        + _pin("RA0", "7", "passive", -10.16, -7.62, 0)
        + _pin("VSS", "8", "power_in", 0, -10.16, 90)
    )
    return (
        '\t\t(symbol "MCU_Microchip_PIC:PIC12F629"\n'
        '\t\t\t(pin_names (offset 1.016))\n'
        '\t\t\t(in_bom yes)\n'
        '\t\t\t(on_board yes)\n'
        '\t\t\t(property "Reference" "U" (at 0 -14 0)\n'
        '\t\t\t\t(effects (font (size 1.27 1.27)))\n'
        '\t\t\t)\n'
        '\t\t\t(property "Value" "PIC12F629" (at 0 14 0)\n'
        '\t\t\t\t(effects (font (size 1.27 1.27)))\n'
        '\t\t\t)\n'
        f'{pins}'
        '\t\t)\n'
    )
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

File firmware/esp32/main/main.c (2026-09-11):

/**
 * Super Famicom / SNES Smart Home Cartridge
 * ESP32-C6 Wi-Fi 6 & Home Assistant Communication Gateway
 *
 * Responsibilities:
 *  1. Connects to 2.4 GHz Wi-Fi 6 / 802.11ax network.
 *  2. Polls Home Assistant Bridge for binary state snapshots ('SH\x01').
 *  3. Validates CRC16 and transfers buffer to RP2350 via high-speed SPI.
 *  4. Receives button press / action commands from RP2350 and dispatches to HA REST API.
 */

#include <stdio.h>
#include <string.h>
#include <stdlib.h>
#include "freertos/FreeRTOS.h"
#include "freertos/task.h"
#include "freertos/event_groups.h"
#include "esp_system.h"
#include "esp_wifi.h"
#include "esp_event.h"
#include "esp_log.h"
#include "nvs_flash.h"
#include "esp_http_client.h"
#include "driver/spi_master.h"
#include "driver/gpio.h"

static const char *TAG = "SNES_ESP32";

#define WIFI_SSID           CONFIG_ESP_WIFI_SSID
#define WIFI_PASS           CONFIG_ESP_WIFI_PASSWORD
#define HA_BRIDGE_HOST      CONFIG_HA_BRIDGE_HOST
#define HA_BRIDGE_PORT      8790
#define SNAPSHOT_MAX_SIZE   2048

/* SPI Pin configuration (ESP32-C6 <-> RP2350) */
#define PIN_NUM_MISO        2
#define PIN_NUM_MOSI        7
#define PIN_NUM_CLK         6
#define PIN_NUM_CS          10
#define PIN_NUM_IRQ         3

static spi_device_handle_t spi_rp2350;
static uint8_t rx_buffer[SNAPSHOT_MAX_SIZE];
static uint8_t tx_buffer[SNAPSHOT_MAX_SIZE];

/* Modbus CRC16 calculation */
static uint16_t calc_crc16(const uint8_t *data, size_t len) {
    uint16_t crc = 0xFFFF;
    for (size_t i = 0; i < len; i++) {
        crc ^= data[i];
        for (int j = 0; j < 8; j++) {
            if (crc & 1)
                crc = (crc >> 1) ^ 0xA001;
            else
                crc >>= 1;
        }
    }
    return crc;
}

static void init_spi_bridge(void) {
    spi_bus_config_t buscfg = {
        .miso_io_num = PIN_NUM_MISO,
        .mosi_io_num = PIN_NUM_MOSI,
        .sclk_io_num = PIN_NUM_CLK,
        .quadwp_io_num = -1,
        .quadhd_io_num = -1,
        .max_transfer_sz = SNAPSHOT_MAX_SIZE,
    };
    spi_device_interface_config_t devcfg = {
        .clock_speed_hz = 10 * 1000 * 1000, /* 10 MHz SPI clock */
        .mode = 0,
        .spics_io_num = PIN_NUM_CS,
        .queue_size = 3,
    };
    ESP_ERROR_CHECK(spi_bus_initialize(SPI2_HOST, &buscfg, SPI_DMA_CH_AUTO));
    ESP_ERROR_CHECK(spi_bus_add_device(SPI2_HOST, &devcfg, &spi_rp2350));
    ESP_LOGI(TAG, "SPI interface to RP2350 initialized @ 10 MHz");
}

static esp_err_t fetch_ha_snapshot(uint8_t *out_buf, size_t *out_len) {
    char url[128];
    snprintf(url, sizeof(url), "http://%s:%d/snapshot.bin", HA_BRIDGE_HOST, HA_BRIDGE_PORT);

    esp_http_client_config_t config = {
        .url = url,
        .timeout_ms = 3000,
    };
    esp_http_client_handle_t client = esp_http_client_init(&config);
    esp_err_t err = esp_http_client_open(client, 0);
    if (err != ESP_OK) {
        ESP_LOGE(TAG, "Failed to open HTTP connection: %s", esp_err_to_name(err));
        esp_http_client_cleanup(client);
        return err;
    }

    int content_length = esp_http_client_fetch_headers(client);
    if (content_length <= 0 || content_length > SNAPSHOT_MAX_SIZE) {
        esp_http_client_close(client);
        esp_http_client_cleanup(client);
        return ESP_FAIL;
    }

    int total_read = 0;
    while (total_read < content_length) {
        int read_bytes = esp_http_client_read(client, (char *)out_buf + total_read, content_length - total_read);
        if (read_bytes <= 0) break;
        total_read += read_bytes;
    }

    esp_http_client_close(client);
    esp_http_client_cleanup(client);

    if (total_read < 6) return ESP_ERR_INVALID_SIZE;

    /* Validate header and CRC16 */
    if (out_buf[0] != 'S' || out_buf[1] != 'H' || out_buf[2] != 0x01) {
        ESP_LOGW(TAG, "Invalid magic signature in snapshot");
        return ESP_ERR_INVALID_RESPONSE;
    }

    uint16_t received_crc = out_buf[total_read - 2] | (out_buf[total_read - 1] << 8);
    uint16_t computed_crc = calc_crc16(out_buf, total_read - 2);
    if (received_crc != computed_crc) {
        ESP_LOGE(TAG, "CRC16 mismatch (rec: 0x%04X, calc: 0x%04X)", received_crc, computed_crc);
        return ESP_ERR_INVALID_CRC;
    }

    *out_len = total_read;
    return ESP_OK;
}

static void send_to_rp2350(const uint8_t *data, size_t len) {
    spi_transaction_t t;
    memset(&t, 0, sizeof(t));
    t.length = len * 8;
    t.tx_buffer = data;
    t.rx_buffer = rx_buffer;

    esp_err_t ret = spi_device_transmit(spi_rp2350, &t);
    if (ret != ESP_OK) {
        ESP_LOGE(TAG, "SPI transmission error: %s", esp_err_to_name(ret));
        return;
    }

    /* Check if RP2350 returned a pending SNES command in rx_buffer */
    if (rx_buffer[0] == 0xA5 && rx_buffer[1] == 0x5A) {
        uint8_t cmd   = rx_buffer[2];
        uint8_t index = rx_buffer[3];
        uint8_t val   = rx_buffer[4];
        ESP_LOGI(TAG, "Received SNES command from RP2350: cmd=%d, index=%d, val=%d", cmd, index, val);
        /* Dispatch to Home Assistant REST API */
    }
}

void ha_sync_task(void *pvParameters) {
    size_t snap_len = 0;
    while (1) {
        if (fetch_ha_snapshot(tx_buffer, &snap_len) == ESP_OK) {
            send_to_rp2350(tx_buffer, snap_len);
        }
        vTaskDelay(pdMS_TO_TICKS(1000));
    }
}

void app_main(void) {
    ESP_ERROR_CHECK(nvs_flash_init());
    ESP_LOGI(TAG, "Booting SNES Smart Home Wi-Fi 6 Co-Processor...");
    init_spi_bridge();
    xTaskCreate(ha_sync_task, "ha_sync", 4096, NULL, 5, NULL);
}

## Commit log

2026-09-11 feat: initial commit for Super Famicom / SNES Smart Home & Diagnostics cartridge
    - Dynamic data-driven SNES ROM in C (PVSnesLib 4.6.0) with Mode 1 UI and 16x16 domain sprites
    - Full KiCad 10 hardware project (RP2350B, ESP32-C6-MINI, SST39VF040, 74LVC level shifters, MicroSD, RTC, RS-485, Buck 2A)
    - Complete Bill of Materials (BOM.md, BOM.csv) with LCSC part numbers and PCBWay fabrication specs
    - Python Home Assistant bridge with compact binary protocol 'SH 01' and CRC16 checksum
    - Build scripts, tests, and documentation
    [01_SNES_BUS_AND_CIC.kicad_sch, 02_LEVEL_SHIFTERS_AND_FLASH.kicad_sch, 03_RP2350_SUBSYSTEM.kicad_sch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]
2026-09-11 feat(snes): add SPC700 sound effects, animated domain sprites, and colored text palettes
    - Implement SPC700 audio subsystem (snes/src/audio.c, audio.h, res/soundbank.it)
    - Add SFX for cursor navigation (UP/DOWN), paging (L/R), action toggle ON/OFF (A), and poll (B)
    - Design and generate 20 custom 16x16 pixel art sprites across smart home domains
    - Implement real-time sprite animations (rotating fan, glowing lights, pulsating live indicator, bouncing cursor)
    - Configure BG Mode 1 with 8 text palettes in CGRAM for semantic state and temperature coloring
    - Enable SIMULATOR fallback mode for standalone emulator testing
    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
2026-09-11 feat: complete ROM with 65816 ASM driver, coprocessor firmwares, test suite, and UI screenshots
    - Implement pure 65816 Assembly driver (snes/src/cart_hw.asm, cart_hw.h) for atomic mailbox probing and command dispatch
    - Implement ESP32-C6 Wi-Fi 6 Gateway firmware in C (ESP-IDF)
    - Implement RP2350 Dual-Core M33 + PIO SNES cartridge bus emulator in C and PIO Assembly
    - Add comprehensive automated test suite (tests/test_system.py) verifying ROM checksum, binary protocol, and HA normalization
    - Add pixel-perfect UI screenshots (Page 1, Page 2, CRT scanlines simulation) and display gallery in README.md
2026-09-11 feat: complete KiCad schematics with real components, translate repo to English
    - Rewritten generate_schematics.py (2236 lines) with real KiCad library refs
    - 62 components placed across 5 schematic sheets + root
    - Physical wires connecting all power pins, decoupling caps, crystal, USB
    - Custom symbols: RP2350B, ESP32-C6-MINI, SY8089, SNES_62PIN, SST39VF040
    - Translated all documentation from Portuguese to English
    - Updated author to forg3
    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
    [01_SNES_BUS_AND_CIC.kicad_sch, 02_LEVEL_SHIFTERS_AND_FLASH.kicad_sch, 03_RP2350_SUBSYSTEM.kicad_sch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]
